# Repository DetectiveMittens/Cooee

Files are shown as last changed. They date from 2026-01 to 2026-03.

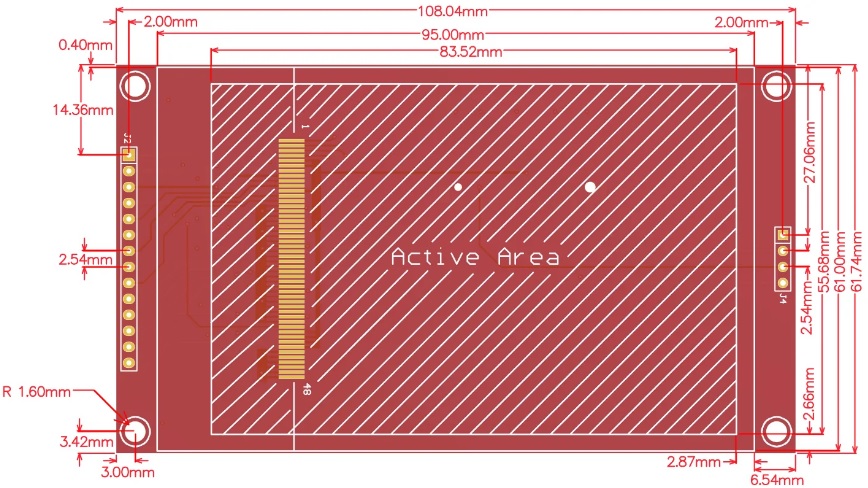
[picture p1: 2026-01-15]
Other Parts/Screen/Elecro_4inch_LCD.jpg

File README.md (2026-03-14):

# Cooee (A LoRa Phone)                           
An open-source phone that can operate without GSM or LTE coverage. Utilising LoRa modulation and mesh networking to enable long range "off-grid" communication.

Come get involved or just chat here! -> [Discord](https://discord.gg/eWgrdjpTFj)
Cooee_renders1

## Target Utilities/Functions
At time of writing (Jan 2026) Popular LoRa mesh networks only aim to support passing of text messages for public and private chat. Cooee aims to provide more of phone the features that consumers are used to

* __Voice calls:__ using 'Codec2' voice can be heavily compressed into small enough packets as to be supported by ~900MHz LoRa bandwidth limitations. Due to the delay that would happen if these packets needed to be retransmitted, calls would likely only be permitted between devices that have only 1 or 0 repeaters required between them.

* __Navigation:__ Using the data from OpenStreetMaps https://www.openstreetmap.org/ pre-loaded onto the device SD card a GPS reciever and infered location data based on signal strength to fixed repeaters of known location, the Cooee device should be able to locate itself well enough for navigation without ever needing a mobile data connection. 

* __Sending images and files:__
While LoRa bandwidth will likely never support sending large files (videos etc) piecemeal file transfers of compressed images (jpgs) should be possible

Cooee_renders2

## Applications / Uses: 
The Cooee should ideally contribute to solving the following problems
  * Distress calls for help in remote locations
  * Basic communication in areas without GSM/LTE infrastructure
  * Dissemination of natural disaster and emergency warnings
  * Marking/Logging GPS locations. Users could tag and share hazards such as landmines (UXO/ERW), fires, vehicle collisions, chemical spills or dangerous wildlife.
  * Navigation in areas without GSM/LTE infrastructure

## Philosophy: 
My dream for this device is that is could demonstrate my ideals for what the future of harware aught to look like. This means deliberately achieving aims in ways which are not the 'best practice', such as;
 * Keeping code simple, using the Arduino framework isntead of ESP-IDF. The idea being that this increases how many people around the world would be able to understand and modify the device firmware, helping ensure that it is kept on track with providing maximum utility to the lives of those people who own one.
 * No electronic components smaller than 805 (no micro-soldering), this allows people to hand solder in repairs and hand assembly the PCB's with minimal equipement
 * SMT components on one side of the PCB only. Again allowing for easy assembly and repair without specialized gear
 * Plastic parts moulded from post consumer waste. Many plastics today claim to be 'recycled' when really they are just 'factory seconds', they have never used and discarded. I would like the plastic components of the Cooee to be injection moulded from recycld post consumer PET bottled pulled from waterways. Many countries in SEA are flooded with drink bottles made of PET. an easily recycled thermoplastic.
 * Hardware ownership. Increasingly, modern mobile devices are not really the property of the customer who paid hundreds, sometimes thousands of dollars to 'own' it. They are not free to modify it or install custom firmware, even creating custom firmware is a task far beyond the capabilities of most. This leaves people at the mercy of whatever bloatware the manufacturers have bundled. This bundled software often; listens to you at all times, sends transcripts of your conversations to corporate servers, advertises products at you, insists on volunteering additional personal details to enable use ect. I think it's high time that the cleverst people in the world put thier efforts towards creating machines that provide all of the utility that benefits us without any of the data harvesting and advertising. Imagine how nice it would be to use a navigator which simply puts your GPS position on a locally loaded map, it doesn't start suffocating your device by chewing up huge amounts of bandwidth or report everywhere you go to a server or try to encourage spending on nearby businesses. Imagine a navigator which just helps you nagivate in the most lightweight and unobtrusive way possible.
 This is the philisophy I want to see applied to all the functions of the Cooee software.

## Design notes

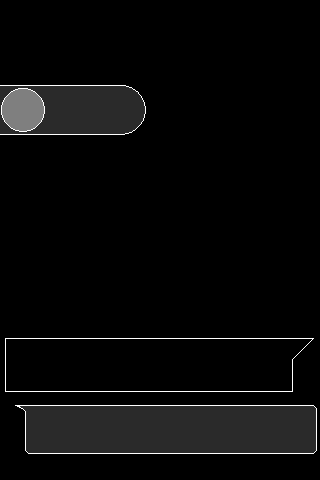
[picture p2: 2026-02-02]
UI_Graphics/messages.bmp

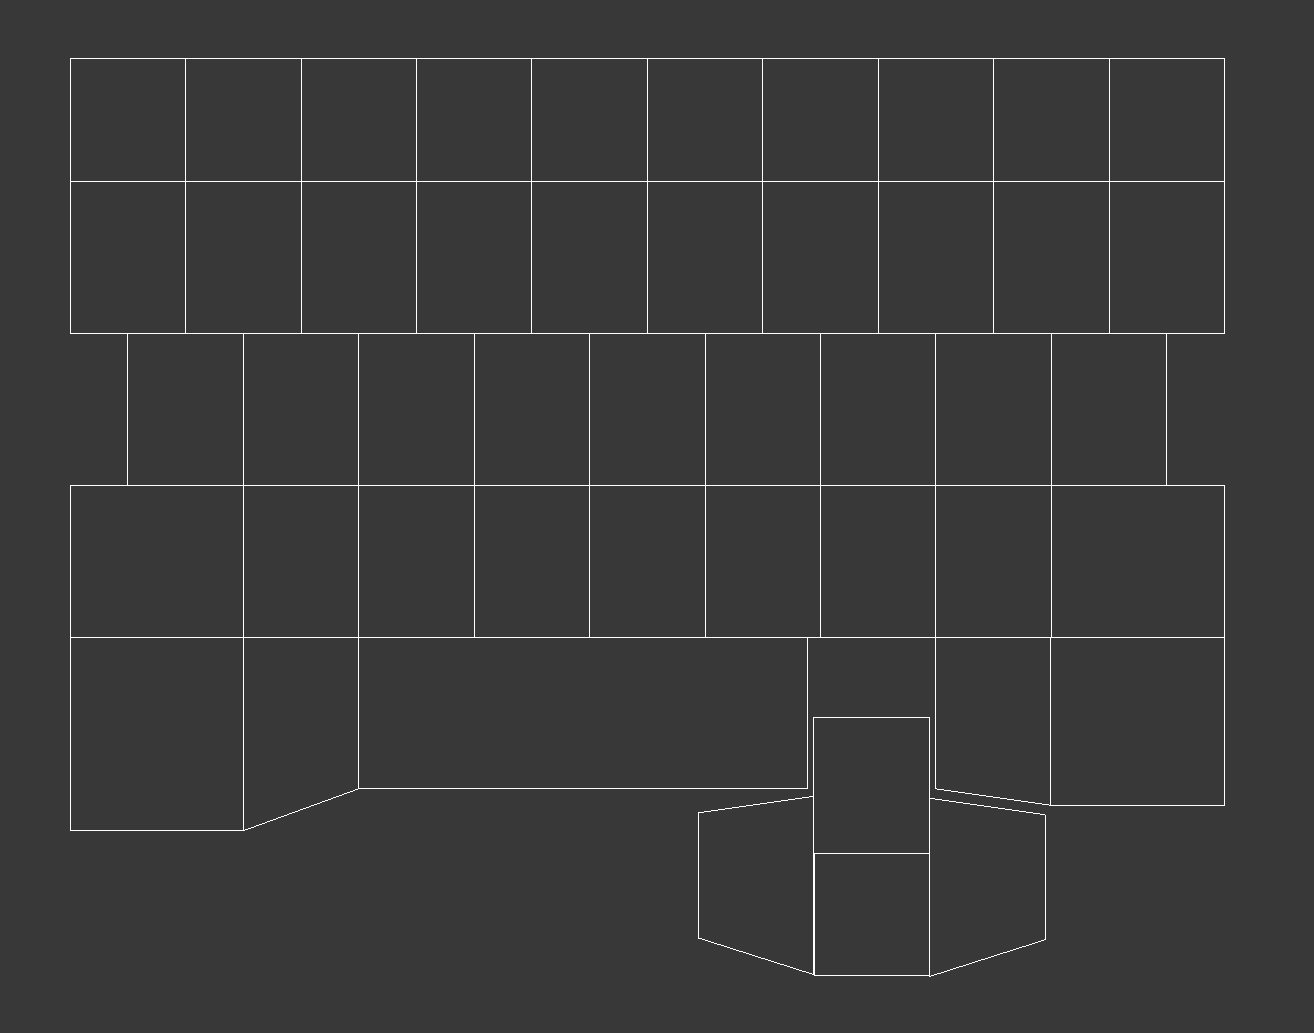
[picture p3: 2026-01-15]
PCB (KiCAD)/key_layout.png

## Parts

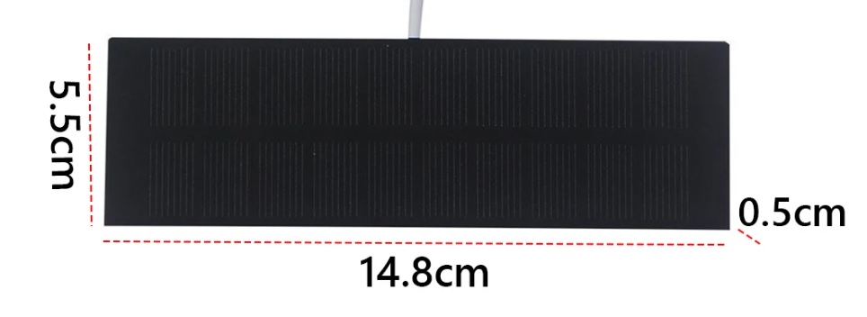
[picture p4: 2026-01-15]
Other Parts/SolarCell/solar_cell.jpg

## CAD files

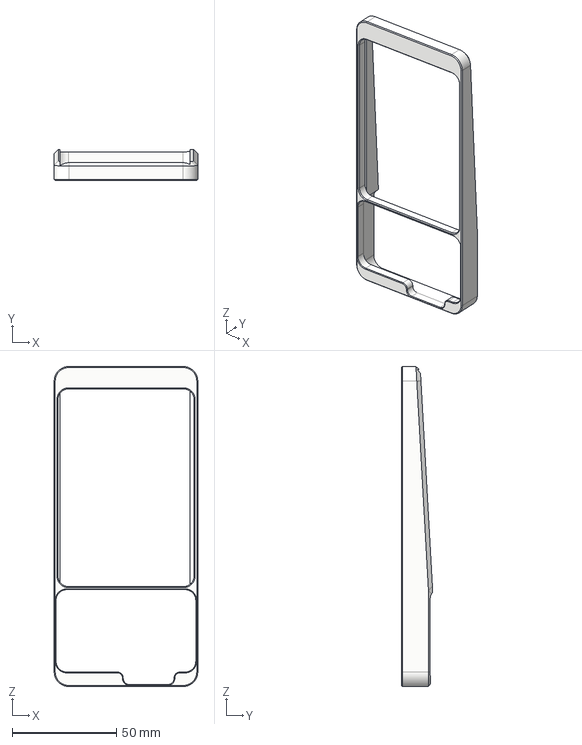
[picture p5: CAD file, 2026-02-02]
3D Prints/Case Prototype.step
68.9 x 15.0 x 153.4 mm

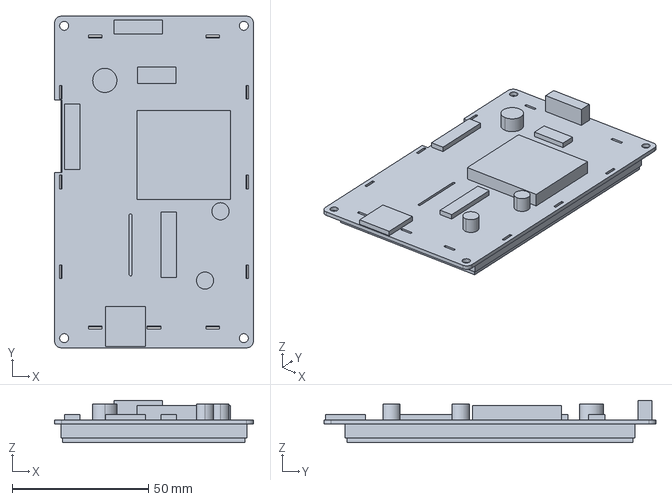
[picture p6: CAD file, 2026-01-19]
Other Parts/Screen/DWIN_DMG48270C043-04WTC.FCStd
73.2 x 121.9 x 15.6 mm

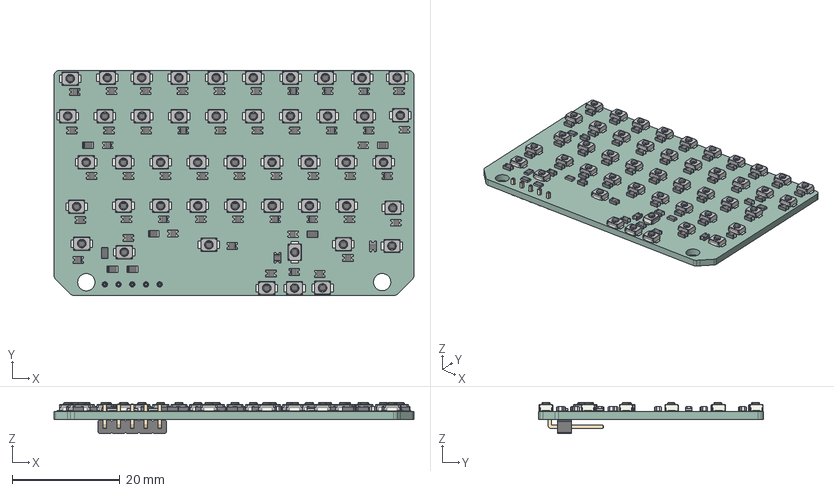
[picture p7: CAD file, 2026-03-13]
PCB (KiCAD)/Cooee_keyboard_68mm.step
66.8 x 41.8 x 5.82 mm
D_0805_2012Metric x 51
SW_SPST_B3U-1000P x 47
R_0805_2012Metric x 7
PinHeader_1x05_P2.54mm_Horizontal
Cooee_keyboard_68mm_PCB

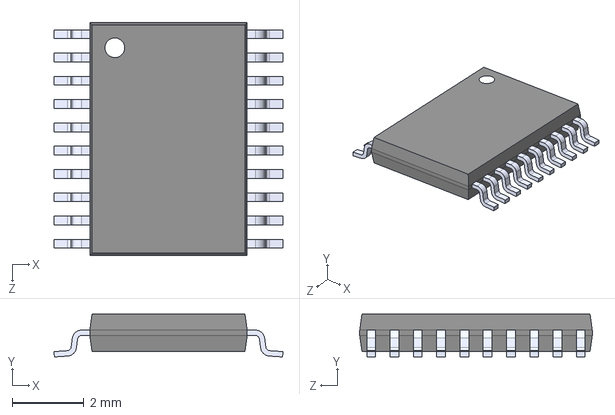
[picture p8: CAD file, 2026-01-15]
PCB (KiCAD)/ICs/PCM5102APWR.STEP
6.40 x 1.20 x 6.50 mm

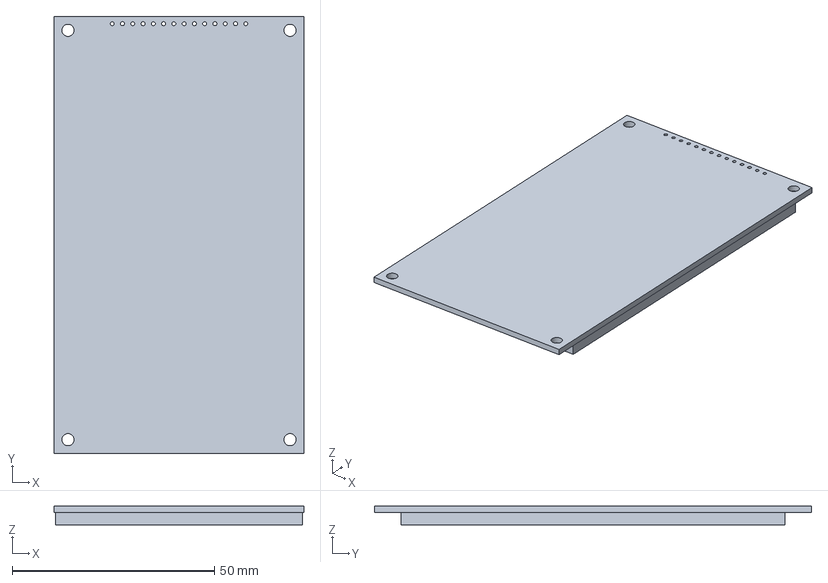
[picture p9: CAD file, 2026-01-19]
Other Parts/Screen/Elecro_4.0_TFT_LCD.FCStd
61.7 x 108.0 x 4.60 mm

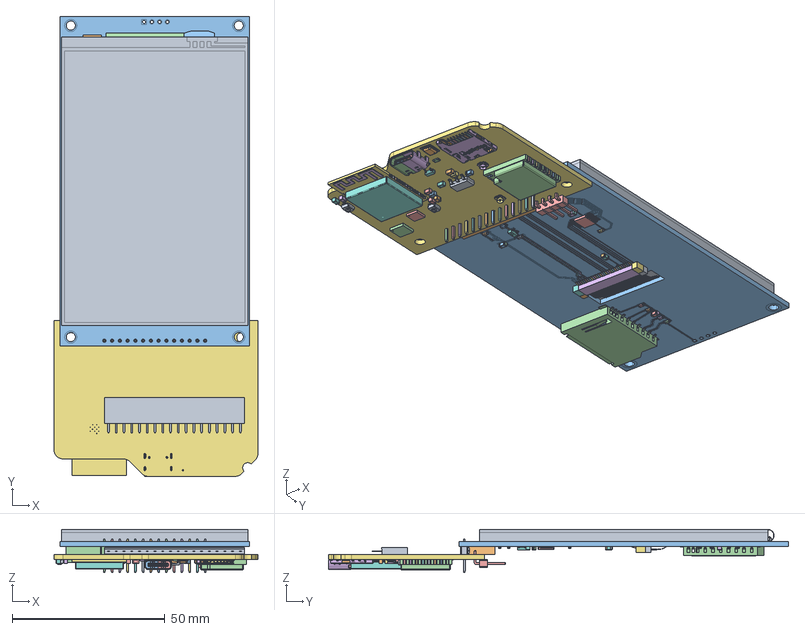
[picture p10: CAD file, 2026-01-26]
PCB (KiCAD)/Cooee_Brains.FCStd
66.8 x 150.7 x 14.2 mm
PinSocket_1x18_P2.54mm_Vertical
PinSocket_1x14_P2.54mm_Horizontal
Cooee_brains 1.3.1
Cooee_brains 1.3.001
Cooee_brains 1.3.002
Cooee_brains 1.3.003
Cooee_brains 1.3.004
Cooee_brains 1.3.005
Cooee_brains 1.3.006
Cooee_brains 1.3.007
Cooee_brains 1.3.008
Cooee_brains 1.3.009
Cooee_brains 1.3.010
Cooee_brains 1.3.011
Cooee_brains 1.3.012
Cooee_brains 1.3.013
Cooee_brains 1.3.014
Cooee_brains 1.3.015
Cooee_brains 1.3.016
Cooee_brains 1.3.017
Cooee_brains 1.3.018
Cooee_brains 1.3.019
Cooee_brains 1.3.020
Cooee_brains 1.3.021
Cooee_brains 1.3.022
Cooee_brains 1.3.023
Cooee_brains 1.3.024
Cooee_brains 1.3.025
Cooee_brains 1.3.026
Cooee_brains 1.3.027
Cooee_brains 1.3.028
Cooee_brains 1.3.029
Cooee_brains 1.3.030
Cooee_brains 1.3.031
Cooee_brains 1.3.032
Cooee_brains 1.3.033
Cooee_brains 1.3.034
Cooee_brains 1.3.035
Cooee_brains 1.3.036
Cooee_brains 1.3.037
Cooee_brains 1.3.038
Cooee_brains 1.3.039
Cooee_brains 1.3.040
Cooee_brains 1.3.041
Cooee_brains 1.3.042
Cooee_brains 1.3.043
Cooee_brains 1.3.044
Cooee_brains 1.3.045
Cooee_brains 1.3.046
Cooee_brains 1.3.047
Cooee_brains 1.3.048
Cooee_brains 1.3.049
Cooee_brains 1.3.050
Cooee_brains 1.3.051
Cooee_brains 1.3.052
Cooee_brains 1.3.053
Cooee_brains 1.3.054
Cooee_brains 1.3.055
Cooee_brains 1.3.056
Cooee_brains 1.3.057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

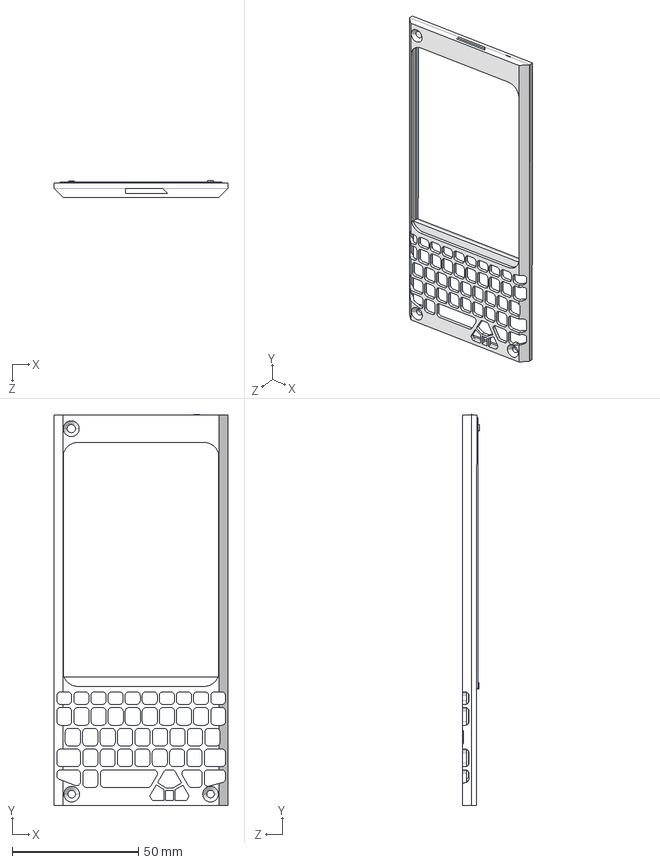
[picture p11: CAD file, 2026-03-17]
Plastic Parts (FreeCAD)/Faceplante_Test2.STEP
68.8 x 154.6 x 6.57 mm

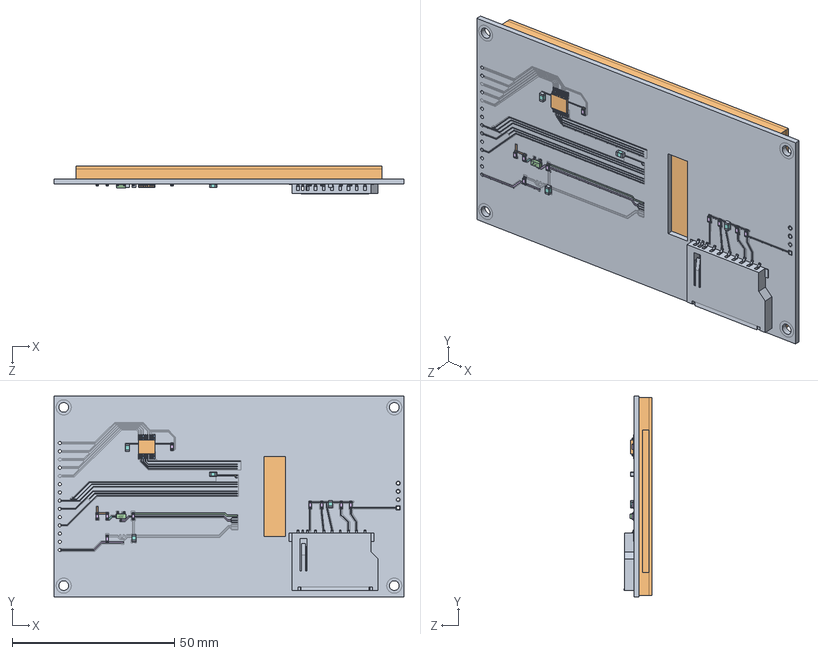
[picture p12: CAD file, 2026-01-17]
Other Parts/Screen/LCD ILI9488 4.0_Simpler.STEP
108.0 x 62.0 x 8.69 mm
pcb_lcd.stp
K_ARDUINO_SD-SCHACHT.stp
XPT204.stp
J3Y.stp
resistor2.stp x 9
ceramic2.stp x 4
tft.stp

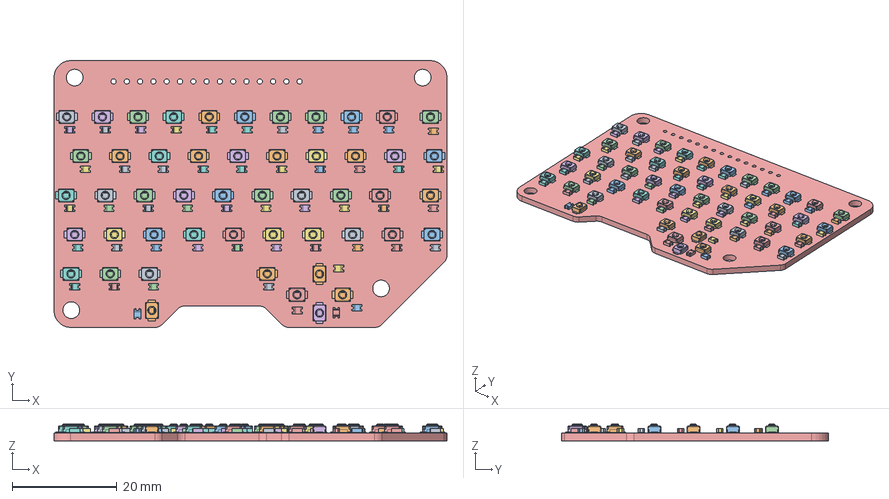
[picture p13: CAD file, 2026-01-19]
PCB (KiCAD)/PCB_Keyboard.FCStd
75.1 x 51.0 x 3.20 mm
D_0805_2012Metric
SW_SPST_B3U-1000P
D_0805_2012Metric001
D_0805_2012Metric002
D_0805_2012Metric003
D_0805_2012Metric004
SW_SPST_B3U-1000P001
SW_SPST_B3U-1000P002
D_0805_2012Metric005
SW_SPST_B3U-1000P003
SW_SPST_B3U-1000P004
SW_SPST_B3U-1000P005
SW_SPST_B3U-1000P006
D_0805_2012Metric006
D_0805_2012Metric007
D_0805_2012Metric008
D_0805_2012Metric009
SW_SPST_B3U-1000P007
D_0805_2012Metric010
SW_SPST_B3U-1000P008
D_0805_2012Metric011
D_0805_2012Metric012
D_0805_2012Metric013
SW_SPST_B3U-1000P009
D_0805_2012Metric014
SW_SPST_B3U-1000P010
SW_SPST_B3U-1000P011
SW_SPST_B3U-1000P012
SW_SPST_B3U-1000P013
SW_SPST_B3U-1000P014
D_0805_2012Metric015
SW_SPST_B3U-1000P015
D_0805_2012Metric016
SW_SPST_B3U-1000P016
SW_SPST_B3U-1000P017
SW_SPST_B3U-1000P018
SW_SPST_B3U-1000P019
SW_SPST_B3U-1000P020
D_0805_2012Metric017
D_0805_2012Metric018
D_0805_2012Metric019
SW_SPST_B3U-1000P021
D_0805_2012Metric020
SW_SPST_B3U-1000P022
D_0805_2012Metric021
SW_SPST_B3U-1000P023
SW_SPST_B3U-1000P024
D_0805_2012Metric022
SW_SPST_B3U-1000P025
SW_SPST_B3U-1000P026
SW_SPST_B3U-1000P027
D_0805_2012Metric023
D_0805_2012Metric024
D_0805_2012Metric025
D_0805_2012Metric026
SW_SPST_B3U-1000P028
SW_SPST_B3U-1000P029
D_0805_2012Metric027
D_0805_2012Metric028
D_0805_2012Metric029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

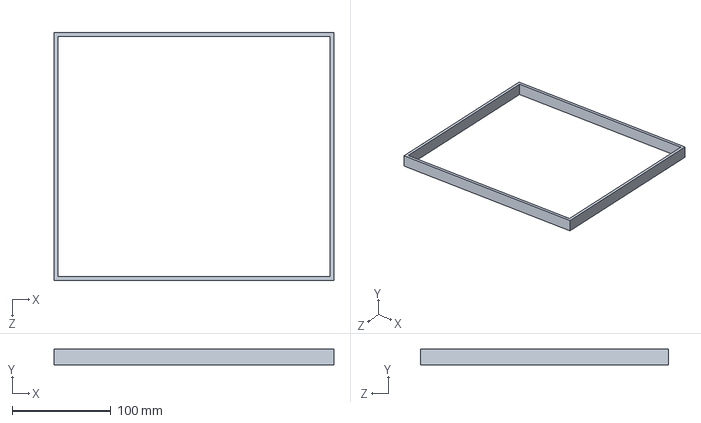
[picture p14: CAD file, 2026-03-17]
Plastic Parts (FreeCAD)/Centering_Frame.SLDPRT
284.1 x 16.0 x 252.0 mm

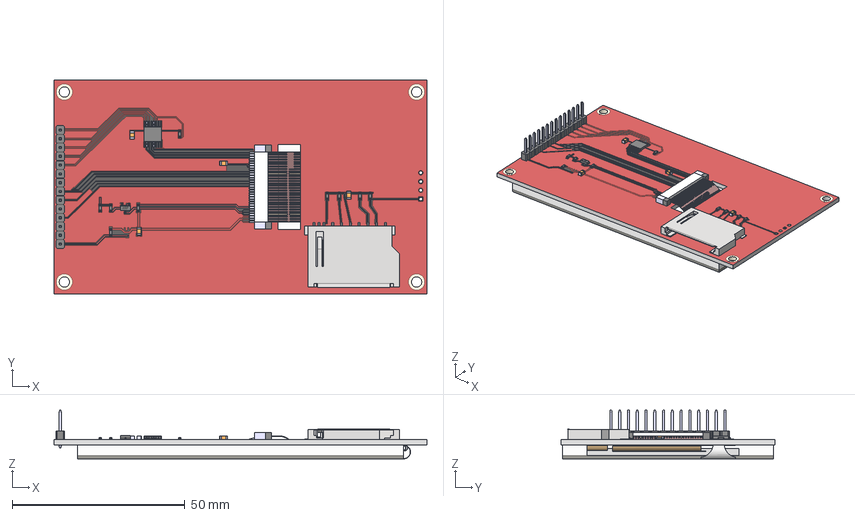
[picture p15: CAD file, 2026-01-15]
Other Parts/Screen/LCD ILI9488 4.0.stp
108.0 x 62.0 x 14.1 mm
pcb_lcd
K_ARDUINO_SD-SCHACHT
XPT204
Connector
J3Y
PINx14
resistor2 x 9
ceramic2 x 4
tft
ribbon_cable_1

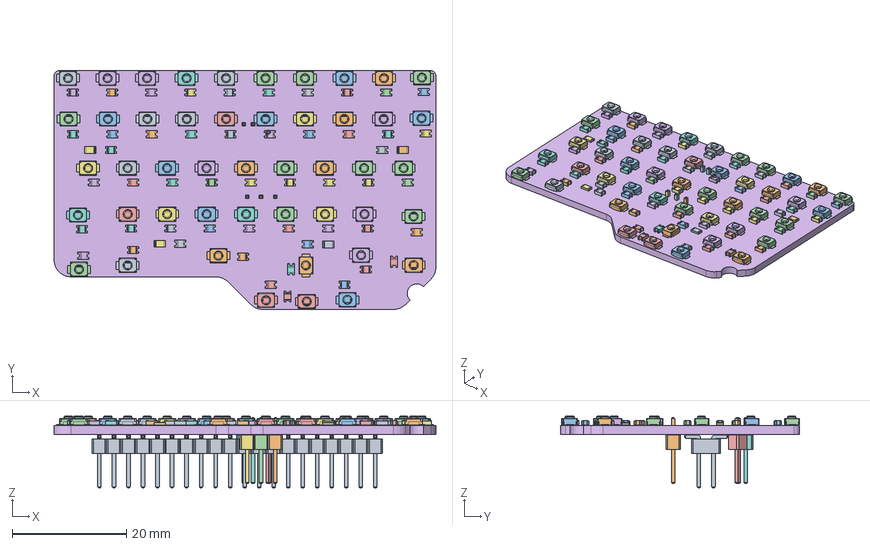
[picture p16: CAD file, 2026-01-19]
PCB (KiCAD)/PCB_Keyboard_68mm.FCStd
66.8 x 41.8 x 12.6 mm
D_0805_2012Metric
SW_SPST_B3U-1000P
D_0805_2012Metric001
D_0805_2012Metric002
D_0805_2012Metric003
D_0805_2012Metric004
SW_SPST_B3U-1000P001
SW_SPST_B3U-1000P002
D_0805_2012Metric005
D_0805_2012Metric006
SW_SPST_B3U-1000P003
SW_SPST_B3U-1000P004
SW_SPST_B3U-1000P005
D_0805_2012Metric007
D_0805_2012Metric008
D_0805_2012Metric009
D_0805_2012Metric010
SW_SPST_B3U-1000P006
D_0805_2012Metric011
SW_SPST_B3U-1000P007
D_0805_2012Metric012
D_0805_2012Metric013
D_0805_2012Metric014
SW_SPST_B3U-1000P008
SW_SPST_B3U-1000P009
SW_SPST_B3U-1000P010
SW_SPST_B3U-1000P011
SW_SPST_B3U-1000P012
SW_SPST_B3U-1000P013
D_0805_2012Metric015
SW_SPST_B3U-1000P014
D_0805_2012Metric016
SW_SPST_B3U-1000P015
SW_SPST_B3U-1000P016
SW_SPST_B3U-1000P017
SW_SPST_B3U-1000P018
SW_SPST_B3U-1000P019
D_0805_2012Metric017
R_0805_2012Metric
D_0805_2012Metric018
R_0805_2012Metric001
D_0805_2012Metric019
SW_SPST_B3U-1000P020
SW_SPST_B3U-1000P021
D_0805_2012Metric020
SW_SPST_B3U-1000P022
SW_SPST_B3U-1000P023
D_0805_2012Metric021
D_0805_2012Metric022
SW_SPST_B3U-1000P024
SW_SPST_B3U-1000P025
SW_SPST_B3U-1000P026
D_0805_2012Metric023
D_0805_2012Metric024
D_0805_2012Metric025
D_0805_2012Metric026
SW_SPST_B3U-1000P027
D_0805_2012Metric027
D_0805_2012Metric028
D_0805_2012Metric029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

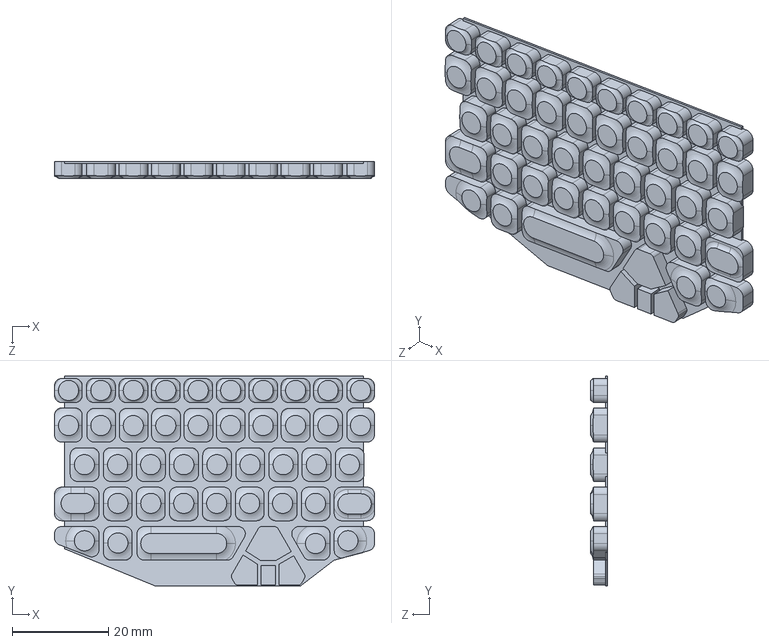
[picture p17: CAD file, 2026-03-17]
Plastic Parts (FreeCAD)/Keys_Test1.STEP
66.6 x 43.7 x 3.45 mm

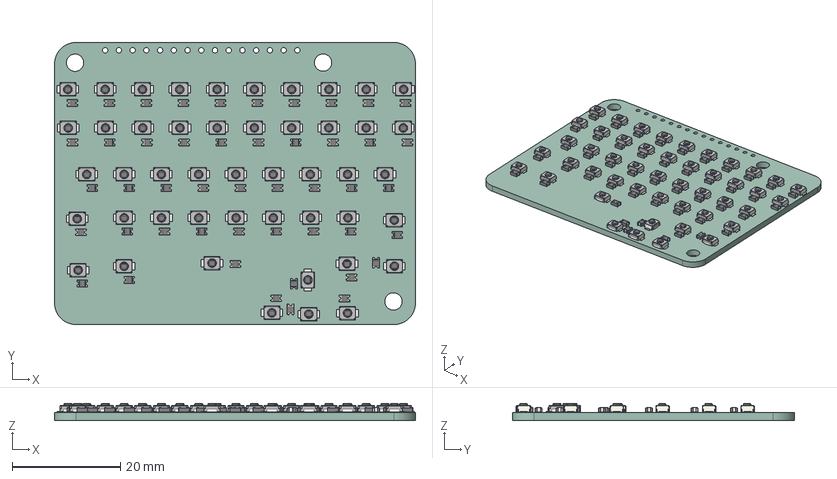
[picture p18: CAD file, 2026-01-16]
PCB (KiCAD)/Cooee_keyboard.step
66.8 x 52.2 x 3.20 mm
D_0805_2012Metric x 47
SW_SPST_B3U-1000P x 47
Cooee_keyboard_68mm_PCB

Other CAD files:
Plastic Parts (FreeCAD)/Case_Assembly.FCStd
Plastic Parts (FreeCAD)/keyboard_outline.DXF
Other Parts/Screen/3D-DMG48270C043-04WTC.stp
Plastic Parts (FreeCAD)/Case2.SLDPRT
Other Parts/Battery/18650.FCStd
PCB (KiCAD)/Cooee_keyboard_75mm.step
Plastic Parts (FreeCAD)/Case.FCStd
Plastic Parts (FreeCAD)/Case2.SLDDRW
Plastic Parts (FreeCAD)/CaseTest.SLDPRT
Plastic Parts (FreeCAD)/Case_2.FCStd
Plastic Parts (FreeCAD)/Motherboard_wScreen.FCStd
Plastic Parts (FreeCAD)/Torch_Lens.SLDPRT

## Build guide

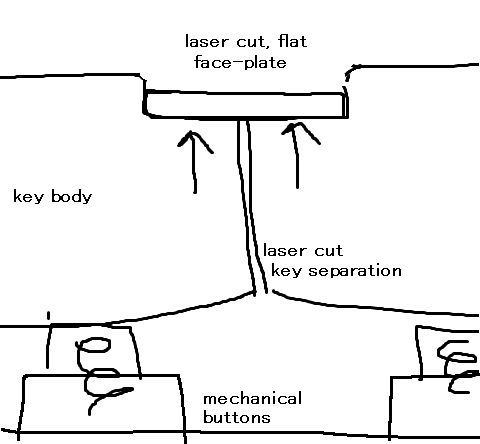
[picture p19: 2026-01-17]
Plastic Parts (FreeCAD)/kayboard_manufacture_plan.jpg

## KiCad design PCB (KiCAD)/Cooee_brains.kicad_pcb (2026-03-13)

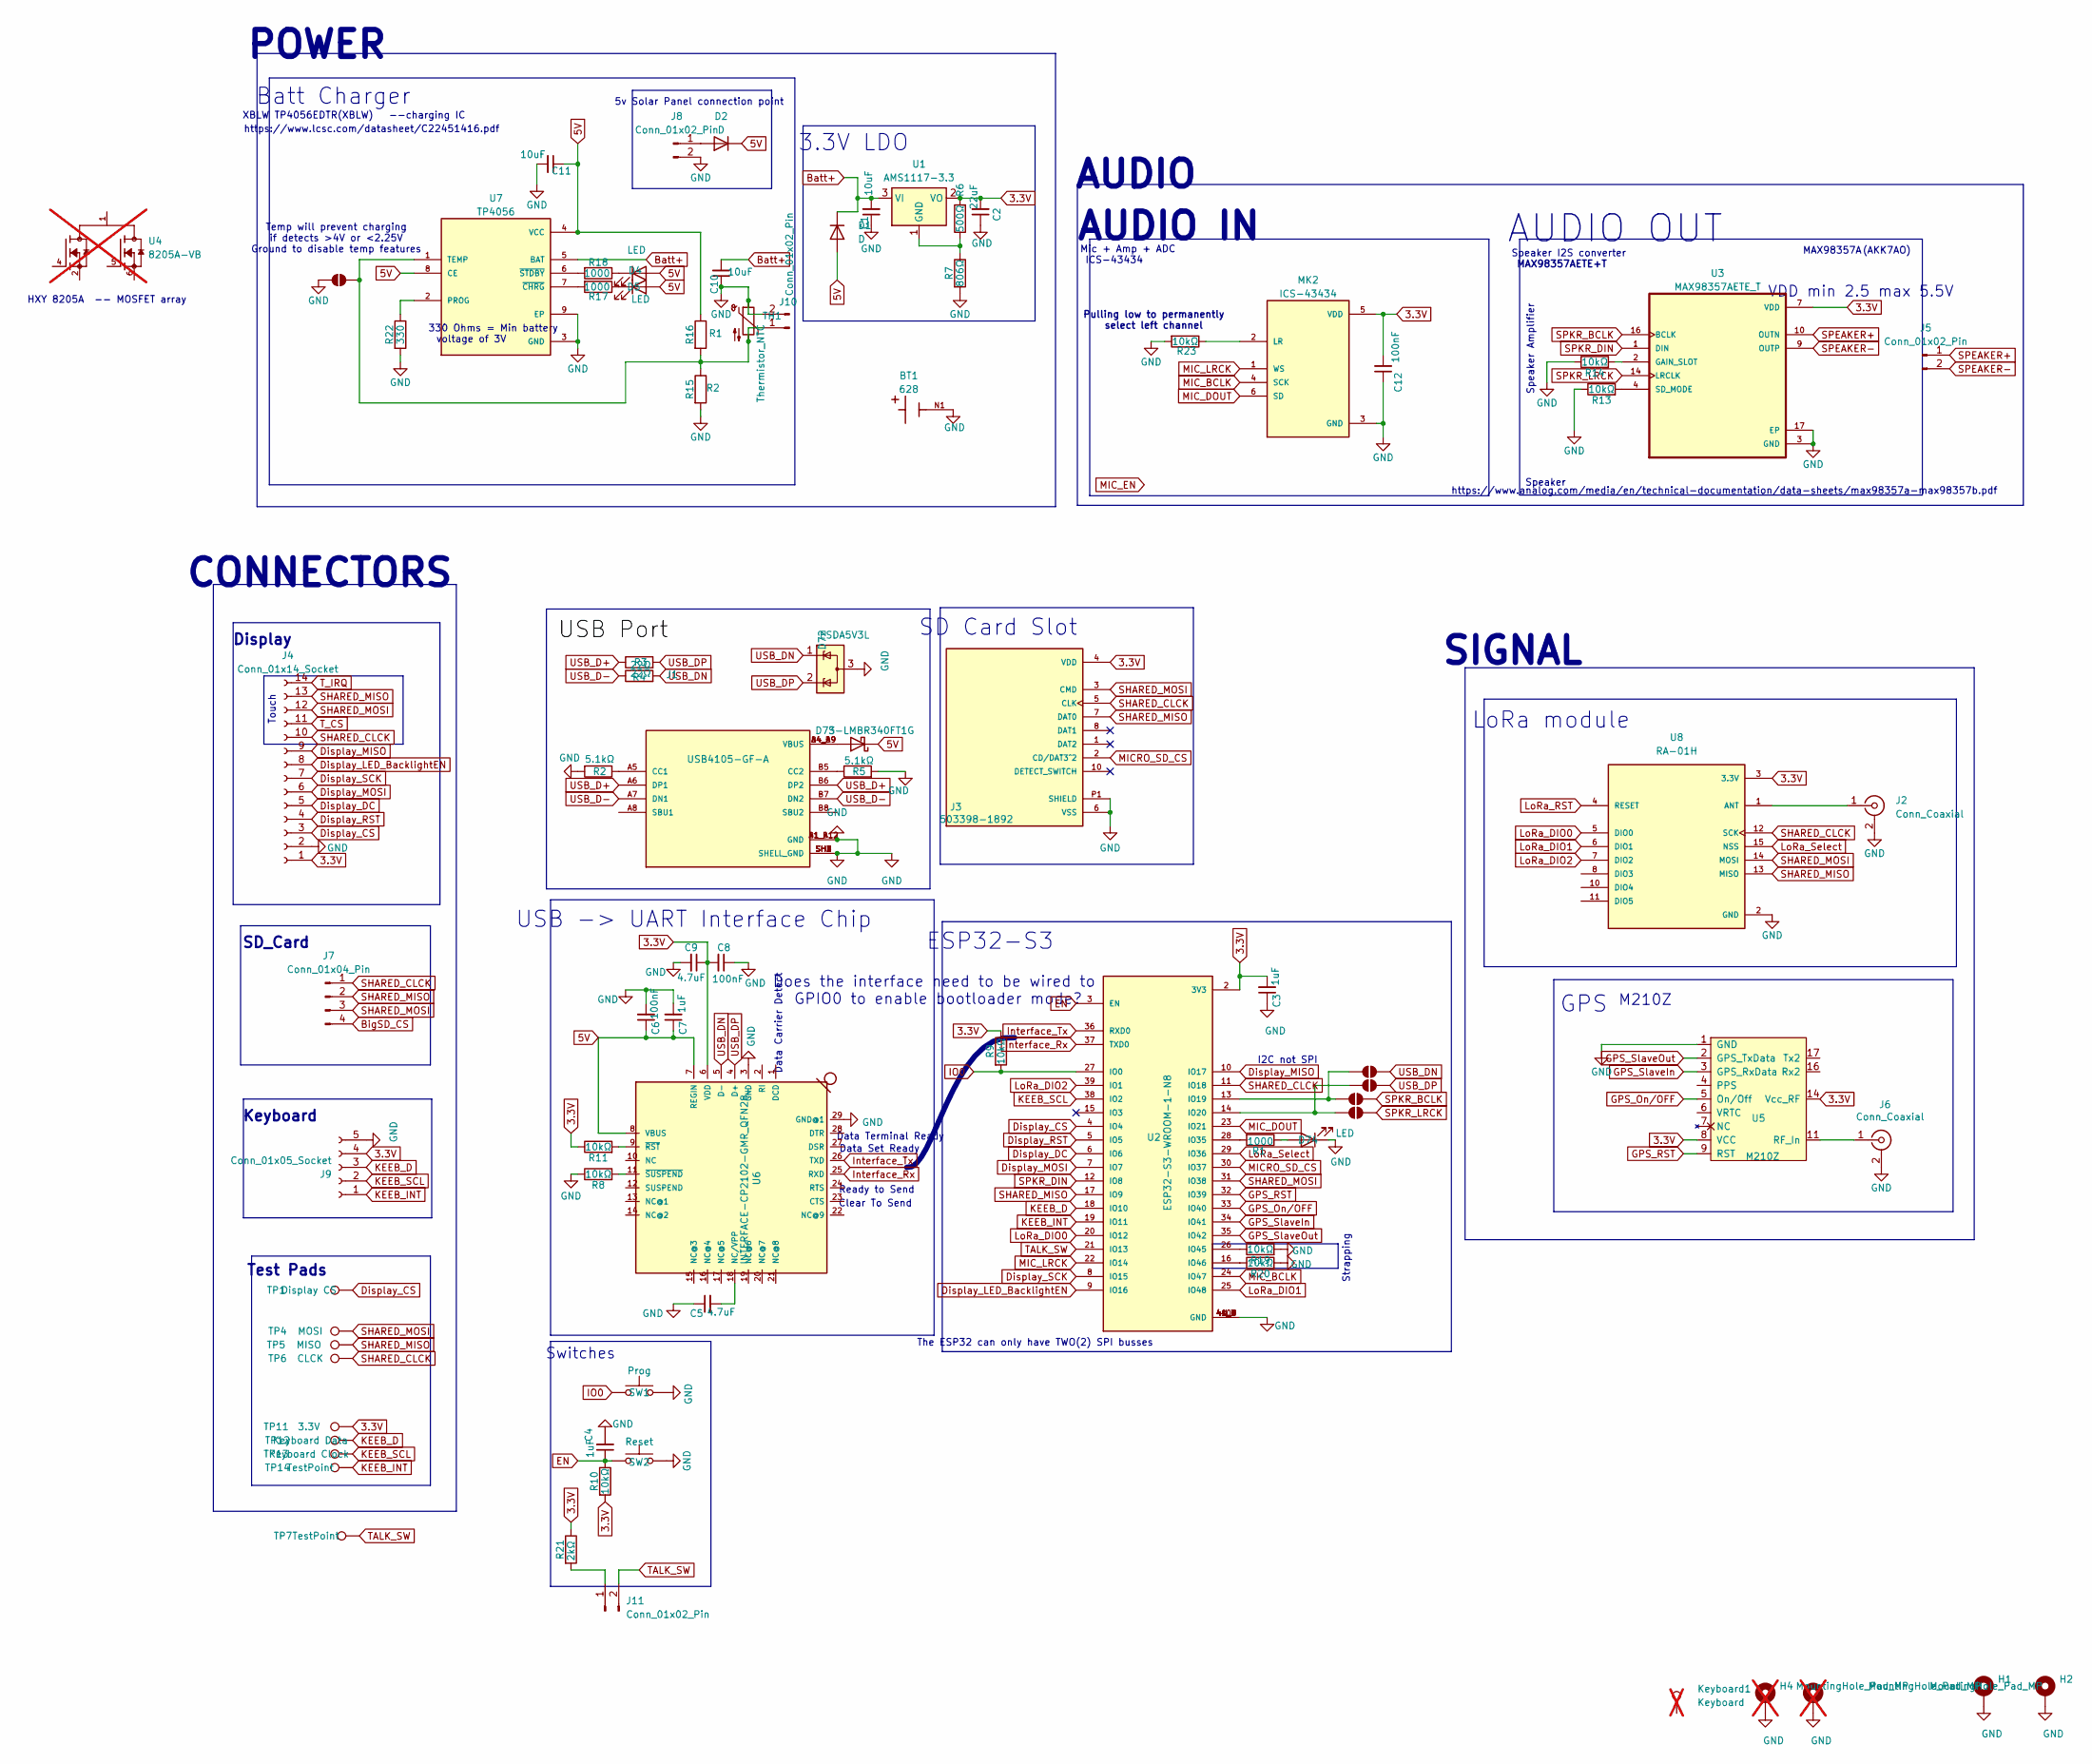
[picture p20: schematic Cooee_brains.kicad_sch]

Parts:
BT1: 628; BAT_628; PARTREV A; DigiKey_Part_Number 36-628-ND
C1, C10, C11: 10uF; C_0805_2012Metric
C2: 22uF; C_0805_2012Metric
C3, C7: 1uF; C_0805_2012Metric
C4: 1uF; C_0805_2012Metric_Pad1.18x1.45mm_HandSolder
C5, C9: 4.7uF; C_0805_2012Metric
C6, C8, C12: 100nF; C_0805_2012Metric
D1, D2: D; D_0805_2012Metric_Pad1.15x1.40mm_HandSolder
D4, D5, D74: LED; C_0805_2012Metric
D72: ESDA5V3L; SOT-23_Handsoldering
D73: S-LMBR340FT1G; D_SOD-123FL
H1, H2: MountingHole_Pad_MP; MountingHole_3.2mm_M3_DIN965_Pad_TopBottom
H3, H4: MountingHole_Pad_MP; MountingHole_3.2mm_M3_DIN965_Pad_TopBottom; not fitted
J1: USB4105-GF-A; USB_C_Receptacle_GCT_USB4105-xx-A_16P_TopMnt_Horizontal
J2, J6: Conn_Coaxial; U.FL_Molex_MCRF_73412-0110_Vertical
J3: 503398-1892; MOLEX_503398-1892; PARTREV 0
J4: Conn_01x14_Socket; PinSocket_1x14_P2.54mm_Horizontal
J5, J8, J10, J11: Conn_01x02_Pin; PinHeader_1x02_P2.54mm_Horizontal
J7: Conn_01x04_Pin; PinHeader_1x04_P2.54mm_Horizontal
J9: Conn_01x05_Socket; PinSocket_1x05_P2.54mm_Horizontal
JP1, JP2, JP3, JP4, JP5: SolderJumper_2_Open; SolderJumper-2_P1.3mm_Open_RoundedPad1.0x1.5mm
Keyboard1: Keyboard; TestPoint_Pad_1.0x1.0mm; not fitted
MK2: ICS-43434; MIC_ICS-43434
R1, R17, R18: 1000; C_0805_2012Metric_Pad1.18x1.45mm_HandSolder
R2, R5: 5.1kΩ; R_0805_2012Metric
R3, R4: 22Ω; R_0805_2012Metric
R6: 500Ω; C_0805_2012Metric_Pad1.18x1.45mm_HandSolder
R7: 806Ω; C_0805_2012Metric_Pad1.18x1.45mm_HandSolder
R8, R9, R10, R11, R13, R14, R19, R20, R23: 10kΩ; C_0805_2012Metric_Pad1.18x1.45mm_HandSolder
R15: R2; C_0805_2012Metric_Pad1.18x1.45mm_HandSolder
R16: R1; C_0805_2012Metric_Pad1.18x1.45mm_HandSolder
R21: 2kΩ; C_0805_2012Metric_Pad1.18x1.45mm_HandSolder
R22: 330; C_0805_2012Metric_Pad1.18x1.45mm_HandSolder
SW1: Prog; SW_SPST_B3U-1000P_MovedText
SW2: Reset; SW_SPST_B3U-1000P_MovedText
TH1: Thermistor_NTC; R_0805_2012Metric_Pad1.20x1.40mm_HandSolder
TP1: Display CS; TestPoint_Pad_1.0x1.0mm
TP4: MOSI; TestPoint_Pad_1.0x1.0mm
TP5: MISO; TestPoint_Pad_1.0x1.0mm
TP6: CLCK; TestPoint_Pad_1.0x1.0mm
TP7, TP14: TestPoint; TestPoint_Pad_1.0x1.0mm
TP11: 3.3V; TestPoint_Pad_1.0x1.0mm
TP12: Keyboard Data; TestPoint_Pad_1.0x1.0mm
TP13: Keyboard Clock; TestPoint_Pad_1.0x1.0mm
U1: AMS1117-3.3; SOT-223-3_TabPin2
U2: ESP32-S3-WROOM-1-N8; ESP32-S3-WROOM-1
U3: MAX98357AETE_T; TQFN-16-1EP_3x3mm_P0.5mm_EP1.6x1.6mm
U4: 8205A-VB; SOP65P640X120-8N; PARTREV NA; not fitted
U5: M210Z
U6: INTERFACE-CP2102-GMR_QFN28_; QFN28G_0.5-5X5MM; MPN CP2102-GMR
U7: TP4056; SOP127P600X175-9N
U8: RA-01H; Ai-Thinker-Ra-01-LoRa; PARTREV V1.0; DigiKey_Part_Number 4570-RA-01HCT-ND

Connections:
3.3V: C2.2, C3.2, C8.2, C9.1, C12.2, J3.4 (VDD), J4.1, J9.4, MK2.5 (VDD), R6.2, R9.1, R10.2, R11.1, R21.1, TP11.1, U1.2 (VO), U2.2 (3V3), U3.7 (VDD), U3.8 (VDD), U5.8 (VCC), U5.14 (Vcc_RF), U6.6 (VDD), U8.3 (3.3V)
5V: C6.1, C7.1, C11.1, D1.2 (A), D2.1 (K), D4.2 (A), D5.2 (A), D73.1 (K), R16.1, U6.7 (REGIN), U6.8 (VBUS), U7.4 (VCC), U7.8 (CE)
Batt+: C1.2, C10.2, D1.1 (K), U1.3 (VI), U7.5 (BAT)
BigSD_CS: J7.4
Display_CS: J4.3, TP1.1, U2.4 (IO4)
Display_DC: J4.5, U2.6 (IO6)
Display_LED_BacklightEN: J4.8, U2.9 (IO16)
Display_MISO: J4.9, U2.10 (IO17)
Display_MOSI: J4.6, U2.7 (IO7)
Display_RST: J4.4, U2.5 (IO5)
Display_SCK: J4.7, U2.8 (IO15)
EN: C4.1, R10.1, SW2.1, U2.3 (EN)
GND: BT1.N1, BT1.N2, BT1.N3, C1.1, C2.1, C3.1, C4.2, C5.1, C6.2, C7.2, C8.1, C9.2, C10.1, C11.2, C12.1, D72.3 (A), D74.1 (K), H1.1, H1.MP, H2.1, H2.MP, H3.MP, H4.MP, J1.A1_B12 (GND), J1.B1_A12 (GND), J1.S1, J1.SH1 (SHELL_GND), J1.SH2 (SHELL_GND), J1.SH3 (SHELL_GND), J1.SH4 (SHELL_GND), J2.2 (Ext), J3.6 (VSS), J3.9 (VSS), J3.P1 (SHIELD), J3.P2 (SHIELD), J3.P3 (SHIELD), J3.P4 (SHIELD), J4.2, J6.2 (Ext), J8.2, J9.5, J10.2, JP5.1 (A), MK2.3 (GND), R2.2, R5.2, R7.2, R8.1, R13.1, R14.1, R15.2, R19.2, R20.2, R22.2, R23.2, SW1.2, SW2.2, TH1.1, U2.1 (GND), U2.40 (GND), U2.41, U2.41_1 (GND), U2.41_2 (GND), U2.41_3 (GND), U2.41_4 (GND), U2.41_5 (GND), U2.41_6 (GND), U2.41_7 (GND), U2.41_8 (GND), U2.41_9 (GND), U2.GND, U3.3 (GND), U3.11 (GND), U3.15 (GND), U3.17 (EP), U5.1 (GND), U6.3 (GND), U6.29 (GND@1), U7.3 (GND), U7.9 (EP), U8.2 (GND), U8.9 (GND), U8.16 (GND)
GPS_On/OFF: U2.33 (IO40), U5.5 (On/Off)
GPS_RST: U2.32 (IO39), U5.9 (RST)
GPS_SlaveIn: U2.34 (IO41), U5.3 (GPS_RxData)
GPS_SlaveOut: U2.35 (IO42), U5.2 (GPS_TxData)
IO0: R9.2, SW1.1, U2.27 (IO0)
Interface_Rx: U2.37 (TXD0), U6.25 (RXD)
Interface_Tx: U2.36 (RXD0), U6.26 (TXD)
KEEB_D: J9.3, TP12.1, U2.18 (IO10)
KEEB_INT: J9.1, TP14.1, U2.19 (IO11)
KEEB_SCL: J9.2, TP13.1, U2.38 (IO2)
LoRa_DIO0: U2.20 (IO12), U8.5 (DIO0)
LoRa_DIO1: U2.25 (IO48), U8.6 (DIO1)
LoRa_DIO2: U2.39 (IO1), U8.7 (DIO2)
LoRa_RST: U8.4 (RESET)
LoRa_Select: U2.29 (IO36), U8.15 (NSS)
MICRO_SD_CS: J3.2 (CD/DAT3^2), U2.30 (IO37)
MIC_BCLK: MK2.4 (SCK), U2.24 (IO47)
MIC_DOUT: MK2.6 (SD), U2.23 (IO21)
MIC_LRCK: MK2.1 (WS), U2.22 (IO14)
unnamed: D2.2 (A), J8.1
unnamed: D4.1 (K), R18.1
unnamed: D5.1 (K), R17.1
unnamed: D73.2 (A), J1.A4_B9 (VBUS), J1.B4_A9 (VBUS)
unnamed: D74.2 (A), R1.1
unnamed: J1.A5 (CC1), R2.1
unnamed: J1.B5 (CC2), R5.1
unnamed: J2.1 (In), U8.1 (ANT)
unnamed: J6.1 (In), U5.11 (RF_In)
unnamed: J10.1, JP5.2 (B), R15.1, R16.2, TH1.2, U7.1 (TEMP)
unnamed: J11.1, R21.2
unnamed: JP1.1 (A), JP3.1 (A), U2.13 (IO19)
unnamed: JP2.1 (A), JP4.1 (A), U2.14 (IO20)
unnamed: MK2.2 (LR), R23.1
unnamed: R6.1, R7.1, U1.1 (GND)
unnamed: R1.2, U2.28 (IO35)
unnamed: R19.1, U2.26 (IO45)
unnamed: R20.1, U2.16 (IO46)
unnamed: R14.2, U3.2 (GAIN_SLOT)
unnamed: R13.2, U3.4 (SD_MODE)
unnamed: U4.1, U4.8
unnamed: U4.2, U4.3
unnamed: U4.6, U4.7
unnamed: C5.2, U6.18 (NC/VPP)
unnamed: R11.2, U6.9 (~RST)
unnamed: R8.2, U6.11 (~SUSPEND)
unnamed: R22.1, U7.2 (PROG)
unnamed: R17.2, U7.7 (~CHRG)
unnamed: R18.2, U7.6 (~STDBY)
SHARED_CLCK: J3.5 (CLK), J4.10, J7.1, TP6.1, U2.11 (IO18), U8.12 (SCK)
SHARED_MISO: J3.7 (DAT0), J4.13, J7.2, TP5.1, U2.17 (IO9), U8.13 (MISO)
SHARED_MOSI: J3.3 (CMD), J4.12, J7.3, TP4.1, U2.31 (IO38), U8.14 (MOSI)
SPEAKER+: J5.1, U3.10 (OUTN)
SPEAKER-: J5.2, U3.9 (OUTP)
SPKR_BCLK: JP3.2 (B), U3.16 (BCLK)
SPKR_DIN: U2.12 (IO8), U3.1 (DIN)
SPKR_LRCK: JP4.2 (B), U3.14 (LRCLK)
TALK_SW: J11.2, TP7.1, U2.21 (IO13)
T_CS: J4.11
T_IRQ: J4.14
USB_D+: J1.A6 (DP1), J1.B6 (DP2), R3.1
USB_D-: J1.A7 (DN1), J1.B7 (DN2), R4.1
USB_DN: D72.1 (K), JP1.2 (B), R4.2, U6.5 (D-)
USB_DP: D72.2 (K), JP2.2 (B), R3.2, U6.4 (D+)

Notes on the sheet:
SIGNAL
Does the interface need to be wired to GPIO0 to enable bootloader mode?
Data Set Ready
MAX98357AETE+T
Data Carrier Detect
AUDIO
The ESP32 can only have TWO(2) SPI busses
https://www.analog.com/media/en/technical-documentation/data-sheets/max98357a-max98357b.pdf
POWER
Speaker Amplifier
M210Z
https://www.lcsc.com/datasheet/C22451416.pdf
voltage of 3V
XBLW TP4056EDTR(XBLW) --charging IC
Strapping
AUDIO IN
Speaker I2S converter
ESP32-S3
Switches
ICS-43434
HXY 8205A -- MOSFET array
SD Card Slot
Ready to Send
Speaker
VDD min 2.5 max 5.5V
Clear To Send
I2C not SPI
SD_Card
5v Solar Panel connection point
AUDIO OUT
Batt Charger
CONNECTORS
Temp will prevent charging if detects >4V or <2.25V Ground to disable temp features
Pulling low to permanently select left channel
USB -> UART Interface Chip
Keyboard
3.3V LDO
Touch
GPS
Test Pads

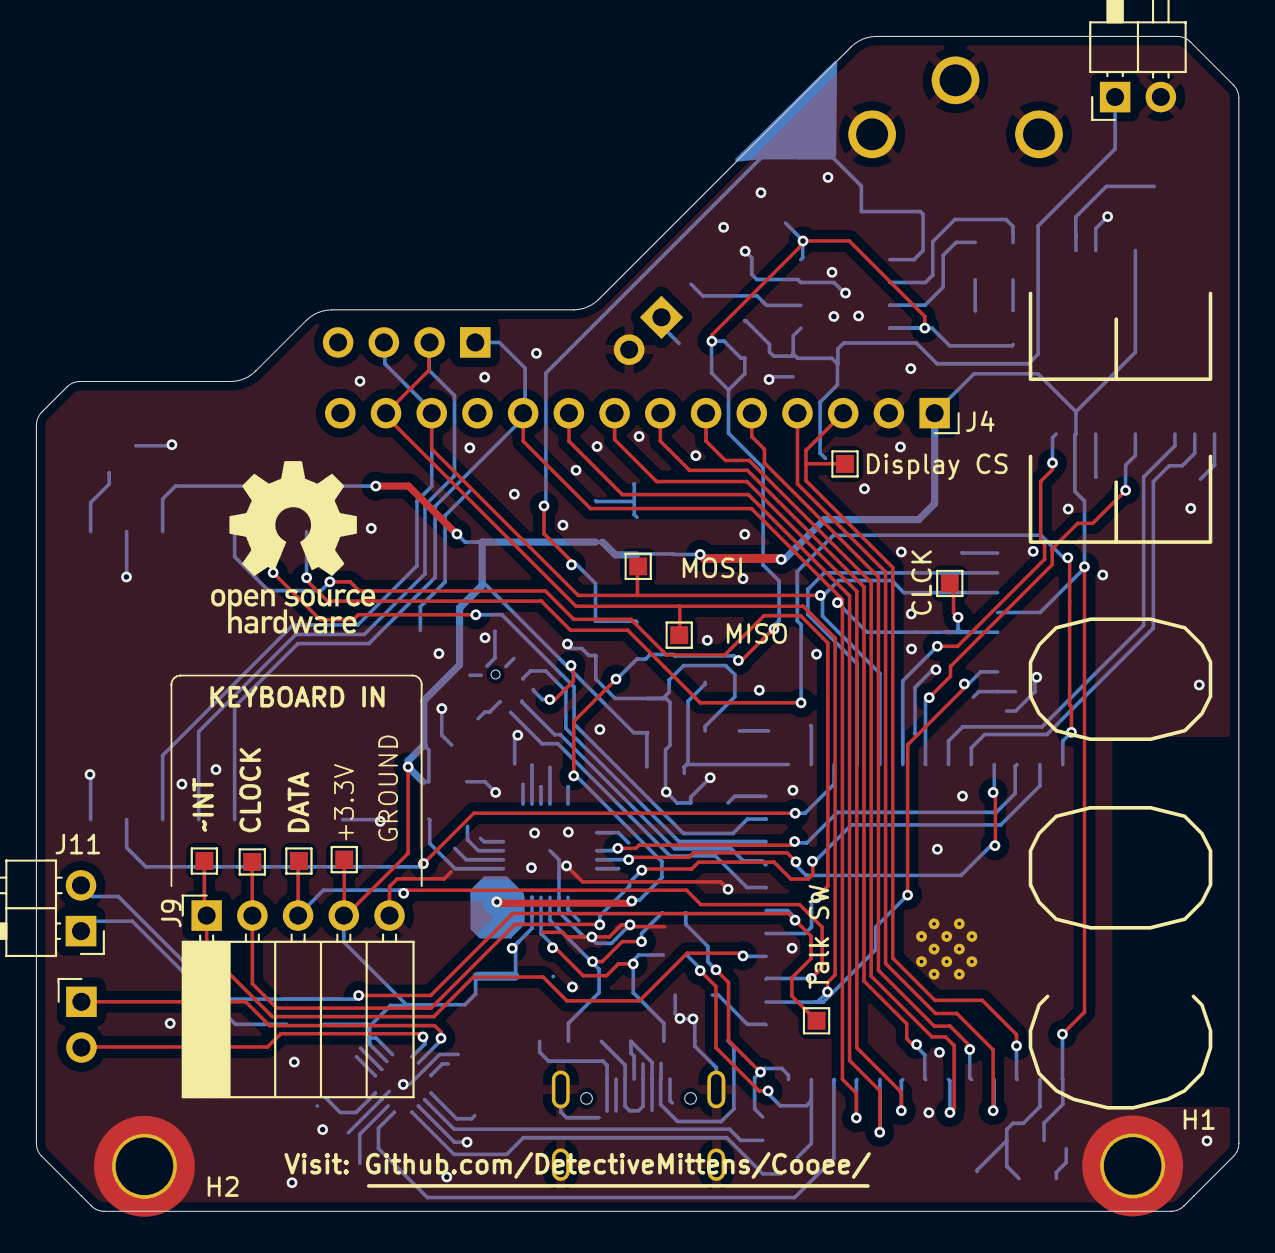
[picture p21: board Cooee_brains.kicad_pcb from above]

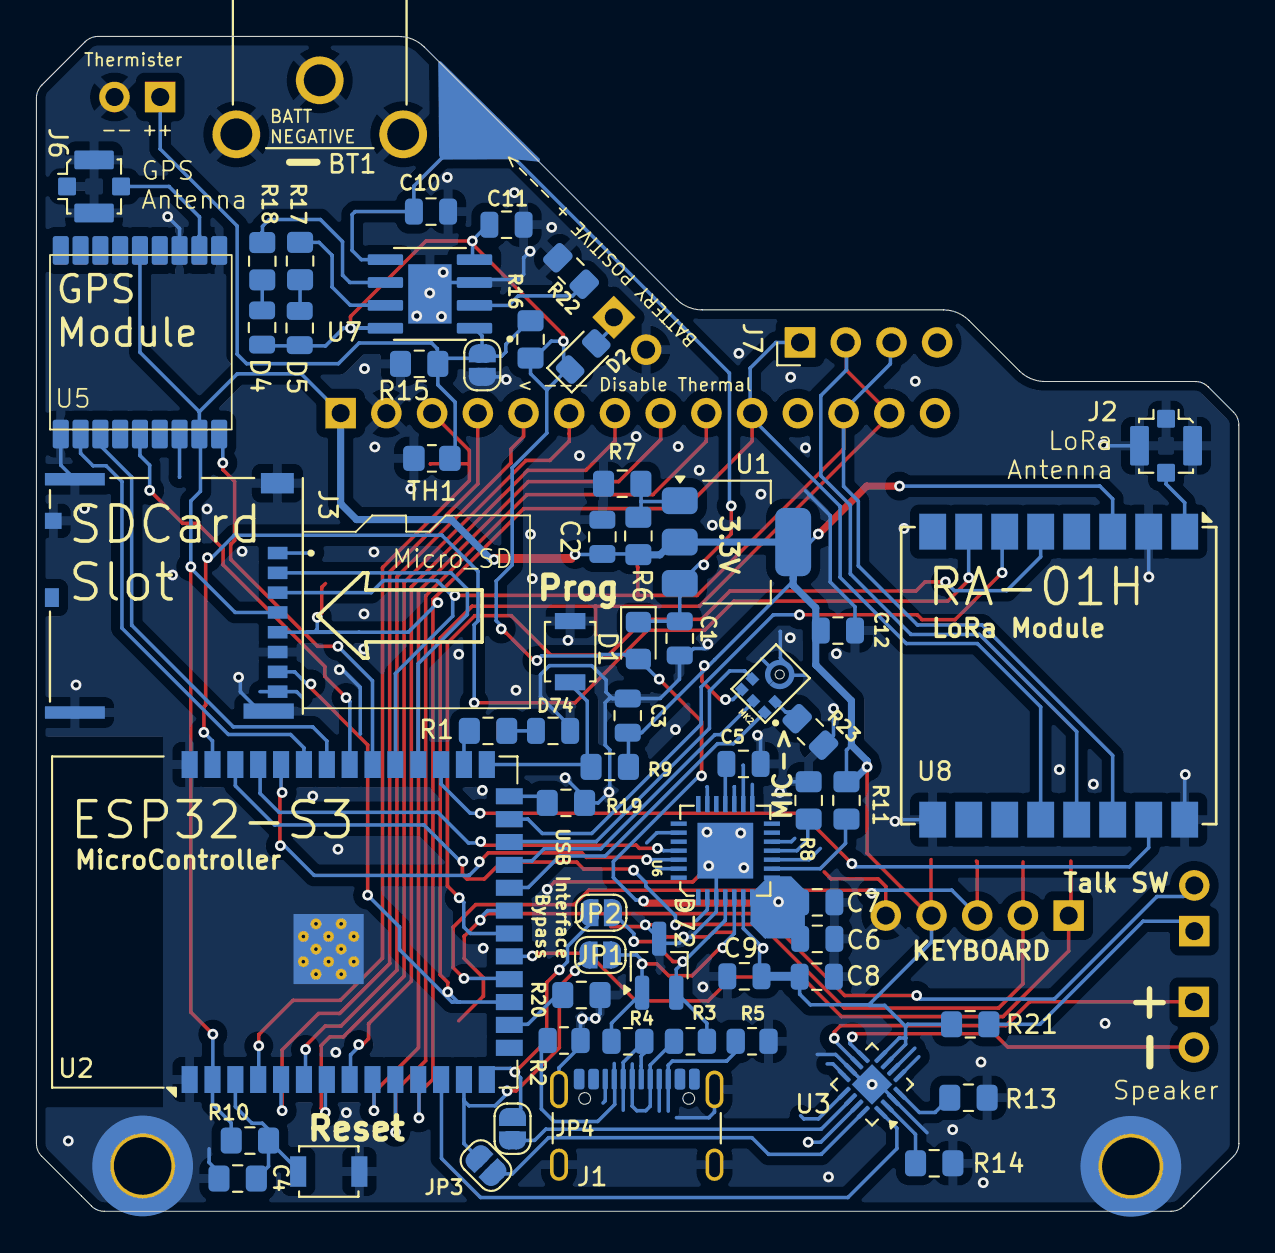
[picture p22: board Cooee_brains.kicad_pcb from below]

Board: 2 copper layers, 66.8 x 65.3 mm, 79 parts (63 on the bottom side), 68 nets.

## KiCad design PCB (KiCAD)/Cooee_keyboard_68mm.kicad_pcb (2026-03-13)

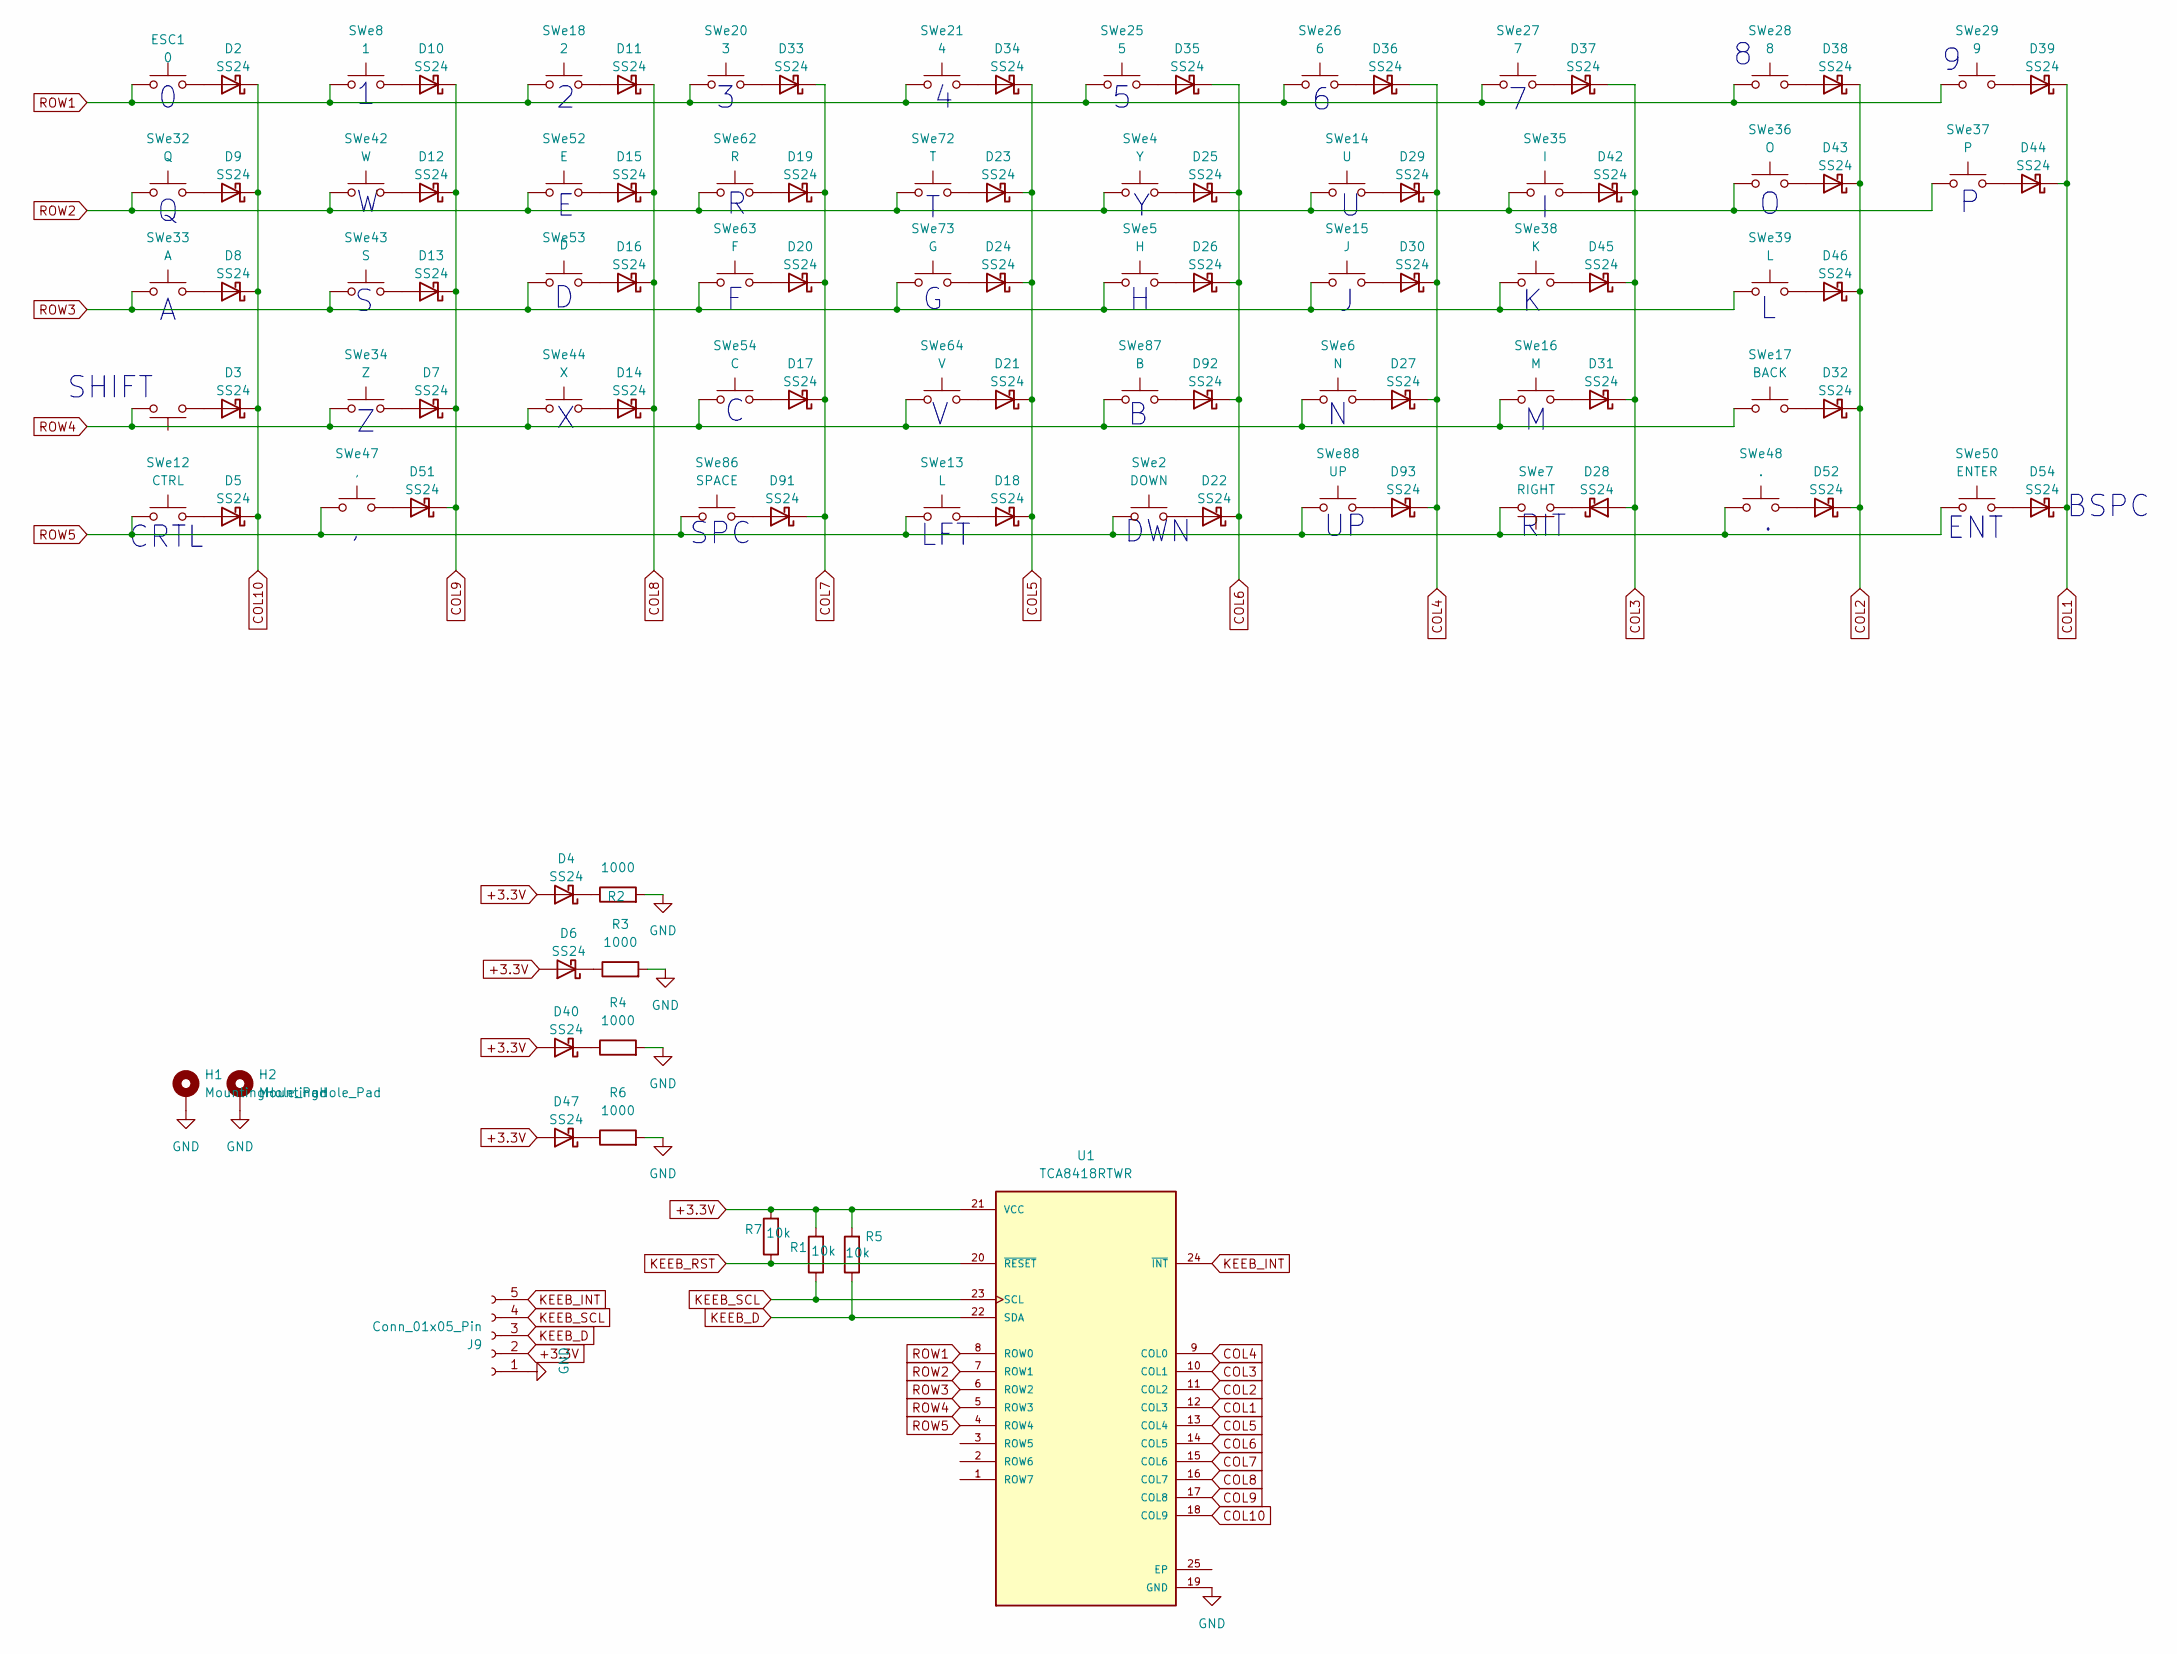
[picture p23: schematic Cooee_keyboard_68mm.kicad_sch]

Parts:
D2, D3, D4, D5, D6, D7, D8, D9, D10, D11, D12, D13, D14, D15, D16, D17, D18, D19, D20, D21, D22, D23, D24, D25, D26, D27, D28, D29, D30, D31, D32, D33, D34, D35, D36, D37, D38, D39, D40, D42, D43, D44, D45, D46, D47, D51, D52, D54, D91, D92, D93: SS24; D_0805_2012Metric
ESC1: 0; SW_SPST_B3U-1000P_MovedText
H1, H2: MountingHole_Pad; MountingHole_3.2mm_M3_DIN965_Pad_TopBottom
J9: Conn_01x05_Pin; PinHeader_1x05_P2.54mm_Horizontal
R1, R5, R7: 10k; R_0805_2012Metric_Pad1.20x1.40mm_HandSolder
R2, R3, R4, R6: 1000; R_0805_2012Metric_Pad1.20x1.40mm_HandSolder
SWe2: DOWN; SW_SPST_B3U-1000P_MovedText
SWe4: Y; SW_SPST_B3U-1000P_MovedText
SWe5: H; SW_SPST_B3U-1000P_MovedText
SWe6: N; SW_SPST_B3U-1000P_MovedText
SWe7: RIGHT; SW_SPST_B3U-1000P_MovedText
SWe8: 1; SW_SPST_B3U-1000P_MovedText
SWe12: CTRL; SW_SPST_B3U-1000P_MovedText
SWe13, SWe39: L; SW_SPST_B3U-1000P_MovedText
SWe14: U; SW_SPST_B3U-1000P_MovedText
SWe15: J; SW_SPST_B3U-1000P_MovedText
SWe16: M; SW_SPST_B3U-1000P_MovedText
SWe17: BACK; SW_SPST_B3U-1000P_MovedText
SWe18: 2; SW_SPST_B3U-1000P_MovedText
SWe20: 3; SW_SPST_B3U-1000P_MovedText
SWe21: 4; SW_SPST_B3U-1000P_MovedText
SWe24: SFT; SW_SPST_B3U-1000P_MovedText
SWe25: 5; SW_SPST_B3U-1000P_MovedText
SWe26: 6; SW_SPST_B3U-1000P_MovedText
SWe27: 7; SW_SPST_B3U-1000P_MovedText
SWe28: 8; SW_SPST_B3U-1000P_MovedText
SWe29: 9; SW_SPST_B3U-1000P_MovedText
SWe32: Q; SW_SPST_B3U-1000P_MovedText
SWe33: A; SW_SPST_B3U-1000P_MovedText
SWe34: Z; SW_SPST_B3U-1000P_MovedText
SWe35: I; SW_SPST_B3U-1000P_MovedText
SWe36: O; SW_SPST_B3U-1000P_MovedText
SWe37: P; SW_SPST_B3U-1000P_MovedText
SWe38: K; SW_SPST_B3U-1000P_MovedText
SWe42: W; SW_SPST_B3U-1000P_MovedText
SWe43: S; SW_SPST_B3U-1000P_MovedText
SWe44: X; SW_SPST_B3U-1000P_MovedText
SWe47: ,; SW_SPST_B3U-1000P_MovedText
SWe48: .; SW_SPST_B3U-1000P_MovedText
SWe50: ENTER; SW_SPST_B3U-1000P_MovedText
SWe52: E; SW_SPST_B3U-1000P_MovedText
SWe53: D; SW_SPST_B3U-1000P_MovedText
SWe54: C; SW_SPST_B3U-1000P_MovedText
SWe62: R; SW_SPST_B3U-1000P_MovedText
SWe63: F; SW_SPST_B3U-1000P_MovedText
SWe64: V; SW_SPST_B3U-1000P_MovedText
SWe72: T; SW_SPST_B3U-1000P_MovedText
SWe73: G; SW_SPST_B3U-1000P_MovedText
SWe86: SPACE; SW_SPST_B3U-1000P_MovedText
SWe87: B; SW_SPST_B3U-1000P_MovedText
SWe88: UP; SW_SPST_B3U-1000P_MovedText
U1: TCA8418RTWR; QFN50P400X400X100-25N; PARTREV G

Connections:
+3.3V: D4.2 (A), D6.2 (A), D40.2 (A), D47.2 (A), J9.2, R1.2, R5.2, R7.2, U1.21 (VCC)
COL1: D39.1 (K), D44.1 (K), D54.1 (K), U1.12 (COL3)
COL2: D32.1 (K), D38.1 (K), D43.1 (K), D46.1 (K), D52.1 (K), U1.11 (COL2)
COL3: D28.2 (A), D31.1 (K), D37.1 (K), D42.1 (K), D45.1 (K), U1.10 (COL1)
COL4: D27.1 (K), D29.1 (K), D30.1 (K), D36.1 (K), D93.1 (K), U1.9 (COL0)
COL5: D18.1 (K), D21.1 (K), D23.1 (K), D24.1 (K), D34.1 (K), U1.13 (COL4)
COL6: D22.1 (K), D25.1 (K), D26.1 (K), D35.1 (K), D92.1 (K), U1.14 (COL5)
COL7: D17.1 (K), D19.1 (K), D20.1 (K), D33.1 (K), D91.1 (K), U1.15 (COL6)
COL8: D11.1 (K), D14.1 (K), D15.1 (K), D16.1 (K), U1.16 (COL7)
COL9: D7.1 (K), D10.1 (K), D12.1 (K), D13.1 (K), D51.1 (K), U1.17 (COL8)
COL10: D2.1 (K), D3.1 (K), D5.1 (K), D8.1 (K), D9.1 (K), U1.18 (COL9)
GND: H1.1, H2.1, J9.1, R2.2, R3.2, R4.2, R6.2, U1.19 (GND)
KEEB_D: J9.3, R5.1, U1.22 (SDA)
KEEB_INT: J9.5, U1.24 (~INT)
KEEB_RST: R7.1, U1.20 (~RESET)
KEEB_SCL: J9.4, R1.1, U1.23 (SCL)
unnamed: D2.2 (A), ESC1.2
unnamed: D3.2 (A), SWe24.2
unnamed: D4.1 (K), R2.1
unnamed: D5.2 (A), SWe12.2
unnamed: D6.1 (K), R3.1
unnamed: D7.2 (A), SWe34.2
unnamed: D8.2 (A), SWe33.2
unnamed: D9.2 (A), SWe32.2
unnamed: D10.2 (A), SWe8.2
unnamed: D11.2 (A), SWe18.2
unnamed: D12.2 (A), SWe42.2
unnamed: D13.2 (A), SWe43.2
unnamed: D14.2 (A), SWe44.2
unnamed: D15.2 (A), SWe52.2
unnamed: D16.2 (A), SWe53.2
unnamed: D17.2 (A), SWe54.2
unnamed: D18.2 (A), SWe13.2
unnamed: D19.2 (A), SWe62.2
unnamed: D20.2 (A), SWe63.2
unnamed: D21.2 (A), SWe64.2
unnamed: D22.2 (A), SWe2.2
unnamed: D23.2 (A), SWe72.2
unnamed: D24.2 (A), SWe73.2
unnamed: D25.2 (A), SWe4.2
unnamed: D26.2 (A), SWe5.2
unnamed: D27.2 (A), SWe6.2
unnamed: D28.1 (K), SWe7.1
unnamed: D29.2 (A), SWe14.2
unnamed: D30.2 (A), SWe15.2
unnamed: D31.2 (A), SWe16.2
unnamed: D32.2 (A), SWe17.2
unnamed: D33.2 (A), SWe20.2
unnamed: D34.2 (A), SWe21.2
unnamed: D35.2 (A), SWe25.2
unnamed: D36.2 (A), SWe26.2
unnamed: D37.2 (A), SWe27.2
unnamed: D38.2 (A), SWe28.2
unnamed: D39.2 (A), SWe29.2
unnamed: D40.1 (K), R4.1
unnamed: D42.2 (A), SWe35.2
unnamed: D43.2 (A), SWe36.2
unnamed: D44.2 (A), SWe37.2
unnamed: D45.2 (A), SWe38.2
unnamed: D46.2 (A), SWe39.2
unnamed: D47.1 (K), R6.1
unnamed: D51.2 (A), SWe47.2
unnamed: D52.2 (A), SWe48.2
unnamed: D54.2 (A), SWe50.2
unnamed: D91.2 (A), SWe86.2
unnamed: D92.2 (A), SWe87.2
unnamed: D93.2 (A), SWe88.2
ROW1: ESC1.1, SWe8.1, SWe18.1, SWe20.1, SWe21.1, SWe25.1, SWe26.1, SWe27.1, SWe28.1, SWe29.1, U1.8 (ROW0)
ROW2: SWe4.1, SWe14.1, SWe32.1, SWe35.1, SWe36.1, SWe37.1, SWe42.1, SWe52.1, SWe62.1, SWe72.1, U1.7 (ROW1)
ROW3: SWe5.1, SWe15.1, SWe33.1, SWe38.1, SWe39.1, SWe43.1, SWe53.1, SWe63.1, SWe73.1, U1.6 (ROW2)
ROW4: SWe6.1, SWe16.1, SWe17.1, SWe24.1, SWe34.1, SWe44.1, SWe54.1, SWe64.1, SWe87.1, U1.5 (ROW3)
ROW5: SWe2.1, SWe7.2, SWe12.1, SWe13.1, SWe47.1, SWe48.1, SWe50.1, SWe86.1, SWe88.1, U1.4 (ROW4)

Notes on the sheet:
ENT
CRTL
LFT
SHIFT
DWN
SPC
RIT
BSPC

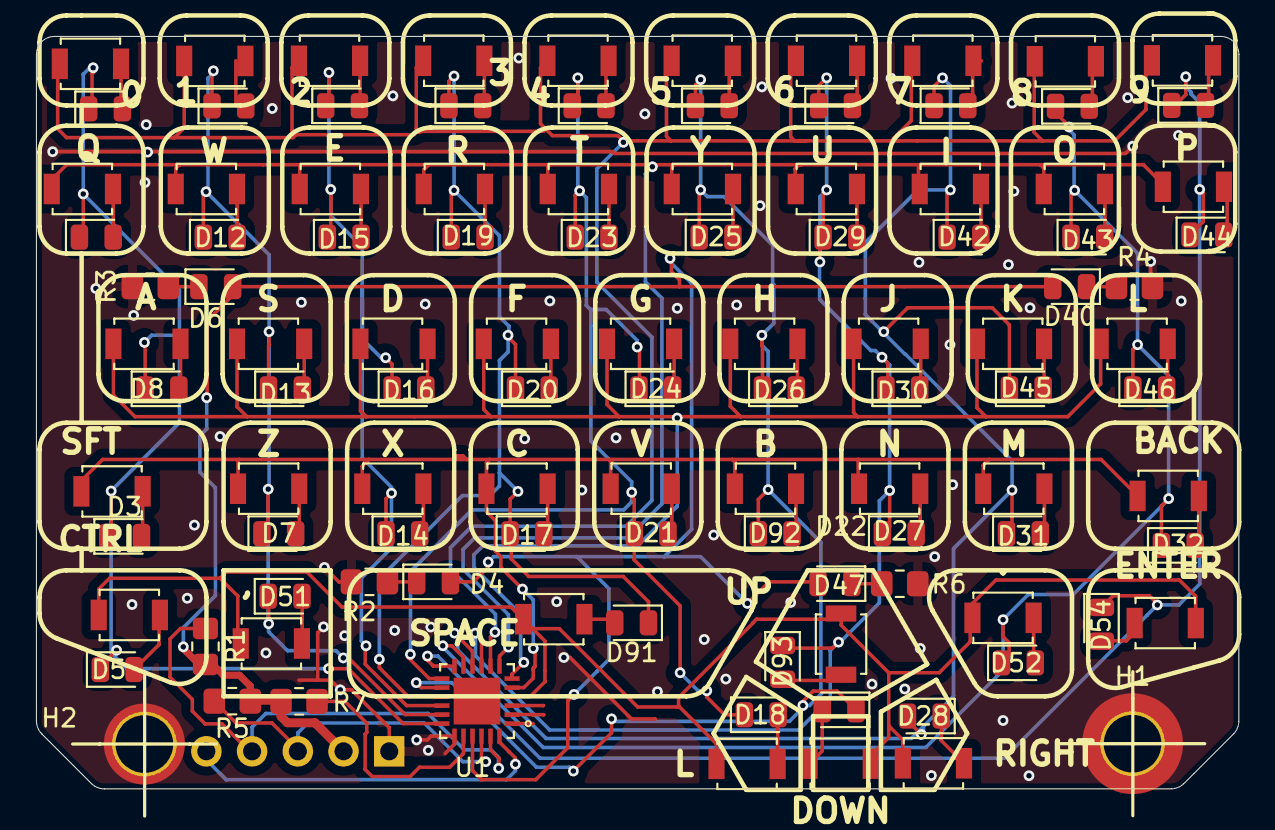
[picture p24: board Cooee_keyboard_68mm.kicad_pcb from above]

Board: 2 copper layers, 66.8 x 41.8 mm, 109 parts (1 on the bottom side), 72 nets.

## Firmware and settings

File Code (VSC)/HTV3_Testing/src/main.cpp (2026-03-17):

/* TODO
count the total number of full (32byte) packets we SHOULD have sent
count the number of times the programm reaches SendLoRaMessage Success
count the total number of recieved 32byte packets on the Rx end!
*/

// 320 samples = 0.04s of audio at 8000Hz
// 32 byte packet = 0.16s of audio at 8000Hz
// 80 bytes = 3200 samples = 0.4s of audio!

// DEBUG, remove later
int packets_filled = 0;
int packets_sent = 0;
int packets_recieved = 0;
int packets_played = 0;
bool prints = true;

#include <Arduino.h>
#include <SPI.h>
#include <Wire.h>
#include <RadioLib.h>
#include <Adafruit_SSD1306.h> //HTV3 OLED drivers
#include <cmath>
#include <cstring> // std::memcpy
#include "FS.h"
#include <LittleFS.h>
#include <driver/i2s.h>

/* - -----     ENABLE/DISABLE FEATURES ----- - */
// #define LCD_4ELECRO
// #define TOUCH_4ELECRO
#define MICROPHONE
#define SPEAKER
// #define GPS
// #define BATTERY
#define HT3_OLED
#define LORA_RADIO

const int bytes_per_sample = 2;
const int recording_length = 64;
const int audio_buffer_size = 1024;
static int16_t locally_saved_recording[audio_buffer_size * recording_length] = {0}; // enough for ~2 seconds of voice samples at 8KHz samplerate
static int16_t decoded_samples[audio_buffer_size * recording_length] = {0};         // enough for ~2 seconds of voice samples at 8KHz samplerate
int decoded_playable_index = 0;
int decoded_played_index = 0;

#ifdef SPEAKER //=====SPEAKER :  AUDIO OUT

#define SPEAKER_I2S_PORT I2S_NUM_1
#define SPEAKER_I2S_DOUT 48
#define SPEAKER_I2S_BCLK 47
#define SPEAKER_I2S_LRC 7

i2s_pin_config_t speaker_i2spins = {
    .bck_io_num = SPEAKER_I2S_BCLK,
    .ws_io_num = SPEAKER_I2S_LRC,
    .data_out_num = SPEAKER_I2S_DOUT,
    .data_in_num = I2S_PIN_NO_CHANGE};

i2s_config_t speaker_i2sconfig = {
    .mode = (i2s_mode_t)(I2S_MODE_MASTER | I2S_MODE_TX),
    .sample_rate = 8000,
    .bits_per_sample = I2S_BITS_PER_SAMPLE_16BIT,
    .channel_format = I2S_CHANNEL_FMT_ONLY_LEFT,
    .communication_format = I2S_COMM_FORMAT_STAND_I2S,
    .intr_alloc_flags = ESP_INTR_FLAG_LEVEL1,
    //.intr_alloc_flags = 0,
    .dma_buf_count = 2,
    .dma_buf_len = audio_buffer_size,
    .use_apll = false};

#endif

#ifdef LCD_4ELECRO
// Elecro 4.0 TFT needs adafruit_st7789 or TFT_eSPI (configured for ST7789 driver)
// the chipset is an ST7789
// resolution is 480x320
#include <TFT_eSPI.h>
TFT_eSPI tft = TFT_eSPI();
#endif

#ifdef TOUCH_4ELECRO
#include <XPT2046_Touchscreen.h>
// make an SPI for the TS
#define TS_MOSI 4
#define TS_MISO 2
#define TS_SCK 3
#define TS_CS 5

SPIClass ts_SPI = SPIClass(HSPI);
XPT2046_Touchscreen ts(TS_CS);
extern XPT2046_Touchscreen ts;
#endif

#ifdef MICROPHONE //=====MICROPHONE :  AUDIO IN

#define MIC_I2S_PORT I2S_NUM_0
#define MIC_I2S_DOUT 4
#define MIC_I2S_BCLK 5
#define MIC_I2S_LRC 3
#define MIC_CS 2
#include <codec2.h> //In the codec2 folder in the library folder

i2s_config_t mic_i2sconfig = {
    .mode = (i2s_mode_t)(I2S_MODE_MASTER | I2S_MODE_RX),
    .sample_rate = 16000, // this refuses to accep any values lower than 16000
    .bits_per_sample = I2S_BITS_PER_SAMPLE_16BIT,
    .channel_format = I2S_CHANNEL_FMT_ONLY_RIGHT,
    //.channel_format = I2S_CHANNEL_FMT_RIGHT_LEFT,
    .communication_format = I2S_COMM_FORMAT_STAND_I2S,
    .intr_alloc_flags = ESP_INTR_FLAG_LEVEL1,
    .dma_buf_count = 2,               // does this just multiply the value below? whats this about...
    .dma_buf_len = audio_buffer_size, // this value is in samples!
    .use_apll = false};

i2s_pin_config_t mic_i2spins = {
    .bck_io_num = MIC_I2S_BCLK,
    .ws_io_num = MIC_I2S_LRC,
    .data_out_num = I2S_PIN_NO_CHANGE,
    .data_in_num = MIC_I2S_DOUT};

#endif

#ifdef HT3_OLED
// Heltec OLED Pins
#define oled_scl 18
#define oled_sda 17
#define oled_rst 21
#define VEXT_PIN 36 // external voltage, needed to send power to the OLED display
#define OLED_WIDTH 128
#define OLED_HEIGHT 64
#endif

#define LED_Orange 1 // the orange LED seems to have a mind of it's own...
#define LED_W 35
#define BOOT_BTN 0

// LoRa module (SX1262) pins
#define LoRa_MOSI 10
#define LoRa_MISO 11
#define LoRa_SCK 9
#define LoRa_nss 8
#define LoRa_dio1 14
#define LoRa_nrst 12
#define LoRa_busy 13

#define LoRa_en_Tx 15
#define LoRa_en_Rx 16

#ifdef HT3_OLED
#define SCREEN_WIDTH 128
#define SCREEN_HEIGHT 64
#define OLED_ADDR 0x3C // Heltec default

Adafruit_SSD1306 display(
    SCREEN_WIDTH,
    SCREEN_HEIGHT,
    &Wire,
    oled_rst);
#endif

//-- AUDIO ENCODING --
struct CODEC2 *codec2_state;
#define ENCODE_FRAME_BYTES 8          // the 40byte frame/packet is built up gradually of 8byte chunks
#define ENCODE_CODEC2_PACKET_BYTES 96 // wait for 5 x 8byte frames before sending over LoRa
static uint8_t bytes_buffer_size = 480;
static uint8_t tx_encode_frame[ENCODE_CODEC2_PACKET_BYTES] = {0}; // 40 byte packet of compressed audio, this is the final array to actually be sent over radio
static uint8_t little_8byte_buffer[8] = {0};
static uint8_t tx_encode_frame_index = 0; // this tracks which of the 5 8byte chunks within the overall 40byte packet we are up to
// static int16_t samples_to_encode[320] = {0}; // this just contains a copy of the last 320 samples of audio which were copied to the locally_saved_recording buffer array, since the encoding function expects 320 samples only!
size_t transmitting_index = 0;

TaskHandle_t encode_task_;
int c2_samples_per_frame_;
int c2_bytes_per_frame_;
int16_t *c2_samples_;
uint8_t *c2_bits_;

// #define configMINIMAL_STACK_SIZE 2048 // Default is usually 256-512

enum Topic : uint8_t
{
  CONTROL = 0,
  TELEMETRY = 1,
  TRANSFER = 2,
  MESSAGE = 3,
  VOICE = 4,
  VIDEO = 5,
  IMAGE = 6,
  LOCATION = 7
};

struct LoRaPacket
{
  uint8_t senderID;     // 1 byte, unique per transmitter
  Topic topicID;        // 1 byte, or more if many topics
  uint8_t targetID;     // 1 byte, unique per target
  uint8_t payload[192]; // adjustable to stay under 200 bytes total
};

SX1262 radio = new Module(LoRa_nss, LoRa_dio1, LoRa_nrst, LoRa_busy);
String oled_message = "OLED Test!";

// function to generate a random string
String random_string(size_t length)
{
  static const char chars[] =
      "0123456789ABCDEFGHIJKLMNOPQRSTUVWXYZabcdefghijklmnopqrstuvwxyz";

  String s;
  for (int i = 0; i < length; i++)
  {
    s += chars[random(0, sizeof(chars) - 1)];
  }

  return s;
}

size_t recording_index = 0;
bool feedback = false;
int16_t GetAudioSamples(int16_t *buffer, size_t samples_to_get, bool give_level = false)
{
  // this must return 1024 samples, other audio buffer sizes don't work with this device
  int16_t input_gain = 40;
  int16_t temp_buffer[samples_to_get];
  size_t bytesRead;
  i2s_read(MIC_I2S_PORT, temp_buffer, samples_to_get * bytes_per_sample, &bytesRead, portMAX_DELAY);

  int16_t samples_average_value = 0;
  for (int i = 0; i < (bytesRead / 2); i += 2)
  {
    temp_buffer[i] *= input_gain;
    samples_average_value += abs(temp_buffer[i] >> 14);

    *(buffer + i / 2) = *(temp_buffer + i);
  }

  samples_average_value /= (bytesRead / 2);
  return samples_average_value;
}

void SaveSamples()
{

  if (prints)
  {
    Serial.println("Here's all the samples: ");
  }

  for (int16_t sample : locally_saved_recording)
  {
    Serial.print(String(sample) + ",");
  }

  /*
  File file = LittleFS.open("/hello.txt", FILE_WRITE);
  if (!file)
  {
    Serial.println("Failed to open file for writing");
    return;
  }

  // write some data
  file.println("Hello ESP32");
  file.close(); // close the file – flushes the buffer

  Serial.println("Wrote /hello.txt");
  */
}

void SendLoRaMessage(String msg)
{
  if (prints)
  {
    Serial.println("SendLoRaMessage() called in text mode");
  }
  int result = radio.transmit(msg);

  if (result == RADIOLIB_ERR_NONE)
  { // the packet was successfully transmitted
    if (prints)
    {
      Serial.println(F("Success!"));
    }
  }
  else if (result == RADIOLIB_ERR_PACKET_TOO_LONG)
  { // the supplied packet was longer than 256 bytes
    Serial.println(F("too long!"));
  }
  else if (result == RADIOLIB_ERR_TX_TIMEOUT)
  { // timeout occured while transmitting packet
    Serial.println(F("timeout occured while transmitting packet!"));
  }
  else
  { // some other error occurred
    Serial.print(F("transmit failed, code "));
    Serial.println(result);
  }
}

void SendLoRaMessage(uint8_t *data, size_t len)
{
  if (prints)
  {
    Serial.println("SendLoRaMessage() called in data mode");
  }

  int result = radio.transmit(data, len);

  if (result == RADIOLIB_ERR_NONE)
  { // the packet was successfully transmitted
    if (prints)
    {
      Serial.println(F("Success!"));
    }
    packets_sent++;
  }
  else if (result == RADIOLIB_ERR_PACKET_TOO_LONG)
  { // the supplied packet was longer than 256 bytes
    Serial.println(F("too long!"));
  }
  else if (result == RADIOLIB_ERR_TX_TIMEOUT)
  { // timeout occured while transmitting packet
    Serial.println(F("Radio timed OUT while sending"));
  }
  else
  { // some other error occurred
    Serial.print(F("transmit failed, code "));
    Serial.println(result);
  }
}

void PutOnScreen(String msg, bool clear)
{
  if (clear)
  {
    oled_message = msg;
  }
  else
  {
    oled_message = oled_message + msg;
  }
}

static byte recievedCompressedBytes[480] = {0};
int ready_for_decoding_index = 0;
int decoded_index = 0;
static int16_t recievedDecompressedSamples[1024 * 5] = {0};
int decompressedPlayed_index = 0;

void RecieveLoRaMessage()
{
  // PutOnScreen("Awaiting message...", false);

  // you can receive data as an Arduino String
  // NOTE: receive() is a blocking method!
  //       See example ReceiveInterrupt for details
  //       on non-blocking reception method.
  // String str;
  // int state = radio.receive(str);

  // you can also receive data as byte array

  byte byteArr[ENCODE_CODEC2_PACKET_BYTES];
  int state = radio.receive(byteArr, ENCODE_CODEC2_PACKET_BYTES);

  if (state == RADIOLIB_ERR_NONE) // everything recieved fine
  {
    if (prints)
    {
      Serial.println("A message has been heard!");
    }
    packets_recieved++;

    // move these successfully heard compressed audio bytes into our static ring buffer for the other compression loop to handle in time
    for (int i = 0; i < ENCODE_CODEC2_PACKET_BYTES; i++)
    {
      recievedCompressedBytes[ready_for_decoding_index + i] = byteArr[i];
    }
    ready_for_decoding_index += ENCODE_CODEC2_PACKET_BYTES;
    if (ready_for_decoding_index > 320) // wrap this buffer
    {
      ready_for_decoding_index -= 320;
    }

    if (prints)
    {
      Serial.println("Recieved bytes added to buffer, ready for decoding then playing. ready_for_decoding_index = " + (String)ready_for_decoding_index);
    }
    /*
    Serial.println(F("success!"));

    // print the data of the packet
    Serial.print(F("[SX1262] Data:\t\t"));
    Serial.println(str);
    PutOnScreen("Recieved: " + str, false);

    // print the RSSI (Received Signal Strength Indicator)
    // of the last received packet
    Serial.print(F("[SX1262] RSSI:\t\t"));
    Serial.print(radio.getRSSI());
    Serial.println(F(" dBm"));

    // print the SNR (Signal-to-Noise Ratio)
    // of the last received packet
    Serial.print(F("[SX1262] SNR:\t\t"));
    Serial.print(radio.getSNR());
    Serial.println(F(" dB"));
    */
  }
  else if (state == RADIOLIB_ERR_RX_TIMEOUT)
  {
    // timeout occurred while waiting for a packet
    if (prints)
    {
      Serial.println(F("Listening..."));
    }
  }
  else if (state == RADIOLIB_ERR_CRC_MISMATCH)
  {
    // packet was received, but is malformed
    Serial.println(F("CRC error!"));
  }
  else
  {
    // some other error occurred
    Serial.print(F("failed, code "));
    Serial.println(state);
  }
}

int GetTransmitDelta()
{
  int transmit_delta = 0;
  if (recording_index < transmitting_index)
  {
    transmit_delta = (recording_index + (audio_buffer_size * recording_length)) - transmitting_index;
  }
  else
  {
    transmit_delta = (recording_index - transmitting_index);
  }
  return transmit_delta;
}

int GetPlayedDelta()
{
  int played_delta = 0;
  if (decoded_playable_index < decoded_played_index)
  {
    played_delta = decoded_playable_index + (audio_buffer_size * recording_length) - decoded_played_index;
  }
  else
  {
    played_delta = decoded_playable_index - decoded_played_index;
  }

  return played_delta;
}

int GetRecieveDelta()
{
  int rx_delta = 0;
  if (ready_for_decoding_index < decoded_index)
  {
    rx_delta = ready_for_decoding_index + 320 - decoded_index;
  }
  else
  {
    rx_delta = (ready_for_decoding_index - decoded_index);
  }
  return rx_delta;
}

void StopSpeaker()
{
  // Stop playback:
  i2s_zero_dma_buffer(SPEAKER_I2S_PORT); // Clear any remaining data
  i2s_stop(SPEAKER_I2S_PORT);
}

void StartSpeaker()
{
  // Restart
  i2s_start(SPEAKER_I2S_PORT);
}

void encode_task(void *param)
{
  Serial.println("encode_task() started!");

  // Initialize the Codec2 object
  codec2_state = codec2_create(CODEC2_MODE_1600);
  if (codec2_state == NULL)
  {
    Serial.println("ERROR: Failed to create codec2 state!");
    return;
  }

  while (true)
  { // loop

    // check if we need to decode (any undecoded audio recieved)
    if (GetRecieveDelta() > 8)
    {
      if (prints)
      {
        Serial.println("More than 8 undecoded bytes in the buffer for decoding");
      }
      byte byteArr[8] = {0};
      for (int i = 0; i < 8; i++) // move 8 bytes into this little buffer to get decoded
      {
        // ensure that this doesn't go out of bounds
        if (decoded_index + i < 320)
        {
          byteArr[i] = recievedCompressedBytes[decoded_index + i];
        }
        else
        {
          byteArr[i] = recievedCompressedBytes[decoded_index + i - 320];
        }
      }
      decoded_index += 8;
      if (decoded_index > 320)
      {
        decoded_index -= 320;
      }

      if (prints)
      {
        Serial.println("Now decoding the 8 byte frame");
      }
      // int16_t decompressed_audio[320];
      codec2_decode(codec2_state, &decoded_samples[decoded_playable_index], byteArr);
      size_t bytes_written;
      decoded_playable_index += 320;
      int decoded_samples_buffer_size = (audio_buffer_size * recording_length);
      if (decoded_playable_index > decoded_samples_buffer_size)
      {
        decoded_playable_index -= decoded_samples_buffer_size;
      }
      if (prints)
      {
        Serial.println("Decoded frame into 320 samples, added to buffer, playable_index is now:" + (String)decoded_playable_index);
      }
      // we can only play whole buffers to the speaker of 1024 samples! so we must store out decodes, little by little
    }

    // check if we need to do an ecode (more than 320 new samples)
    if (GetTransmitDelta() >= 320)
    {
      if (prints)
      {
        Serial.println("transmit_delta above 320, moving samples to encoding buffer. Delta=" + (String)GetTransmitDelta());
      }
      // scrape the next 320 samples from the ring buffer to encode and send

      int16_t samples_to_encode[320] = {0};
      for (int i = 0; i < 320; i++)
      {
        if (transmitting_index + i < (audio_buffer_size * recording_length))
        {
          samples_to_encode[i] = locally_saved_recording[transmitting_index + i]; // copy 1 to 1 if the index stays within the bounds of locally_saved_recording[]
        }
        else
        { // otherwise we need to modify i to stay within bounds
          samples_to_encode[i] = locally_saved_recording[transmitting_index + i - (audio_buffer_size * recording_length)];
        }
      }
      transmitting_index += 320;
      if (transmitting_index >= (audio_buffer_size * recording_length)) // wrap around the array
      {
        transmitting_index -= (audio_buffer_size * recording_length);
      }

      // codec2_encode
      codec2_encode(codec2_state, tx_encode_frame + tx_encode_frame_index, samples_to_encode);
      vTaskDelay(1);

      // Send tx_encode_frame via radio etc
      if (prints)
      {
        Serial.println("320 samples converted to 8 bytes of compressed audio in frame buffer");
      }
      // Store this encoded 320samples -> 8bytes of compressed audio, into the 'tx_encode_frame'  buffer, we will sent it over lora once we collect 40 total bytes
      tx_encode_frame_index += ENCODE_FRAME_BYTES;             // incrememnt by 8bytes
      if (tx_encode_frame_index >= ENCODE_CODEC2_PACKET_BYTES) // packet is full (32 bytes)
      {
        packets_filled++;
        // Serial.println("32 byte frame buffer is full now");
        tx_encode_frame_index = 0;
        if (prints)
        {
          Serial.println("Sending: 32 bytes of comressed audio over LoRa");
        }
        SendLoRaMessage(tx_encode_frame, sizeof(tx_encode_frame));
      }
    }
    else
    {
      // Serial.println("Nothin new to encode...");
      delay(20);
    }
  }

  // this should never get reached, since the loop has no end
  //  cleanup the task before it ends or it will crash the chip
  codec2_destroy(codec2_state);
  vTaskDelete(NULL);
  return;
}

void setup()
{
  Serial.begin(115200);

  /*
  // initialise the file‑system
  Serial.println("Attempting to mount LittleFS.");
  delay(1000);
  if (!LittleFS.begin())
  { // false = mounting failed
    Serial.println("LittleFS mount failed");
    return;
  }
  Serial.println("LittleFS mounted");
  */

#ifdef SPEAKER
  i2s_driver_install(SPEAKER_I2S_PORT, &speaker_i2sconfig, 0, NULL);
  i2s_set_pin(SPEAKER_I2S_PORT, &speaker_i2spins);
#endif

#ifdef MICROPHONE
  i2s_driver_install(MIC_I2S_PORT, &mic_i2sconfig, 0, NULL);
  i2s_set_pin(MIC_I2S_PORT, &mic_i2spins);
#endif

#ifdef LCD_4ELECRO
  Serial.println("Initializing TFT...");
  tft.begin();
  tft.setRotation(0);
  delay(100);
  tft.fillScreen(TFT_BLACK);
  // tft.fillRect(100,100,200,200,TFT_GREEN);
  tft.setTextFont(2);
  tft.setTextSize(1);
  tft.setTextColor(TFT_WHITE);
  Serial.println("TFT Initialized!");
#endif

#ifdef TOUCH_4ELECRO
  ts_SPI.begin(TS_SCK, TS_MISO, TS_MOSI, TS_CS);
  ts.begin(ts_SPI);
  ts.setRotation(2);
#endif

  pinMode(MIC_CS, OUTPUT);
  digitalWrite(MIC_CS, HIGH);
  pinMode(LED_W, OUTPUT);
  pinMode(LED_Orange, OUTPUT);
  pinMode(BOOT_BTN, INPUT_PULLUP);
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
void loop()
{

#ifdef LCD_4ELECRO
  tft.fillScreen(TFT_BLACK);
  tft.setCursor(0, 0);
#endif

#ifdef TOUCH_4ELECRO
  boolean istouched = ts.touched();
  if (istouched)
  {
    // tft.print("a");
    TS_Point p = calibratedPoint(ts.getPoint());
    // tft.print( p.x );
    tft.fillCircle(p.x, p.y, 5, TFT_WHITE);
    tft.drawCircle(p.x, p.y, 50, TFT_WHITE);
  }
#endif

#ifdef HT3_OLED
  display.clearDisplay();
#endif

  if (digitalRead(BOOT_BTN) == LOW) // PRG button pressed down - we speak
  {
    if (!transmitting)
    {
      transmitting = true;
    }
  }
  else // PRG button is up - we listen
  {
    if (transmitting)
    {
      transmitting = false;
      delay(300);
    }
  }

  if (transmitting) // record the MIC_IN adc (should be talking)
  {
    // before we add 2048 bytes of data to locally_saved_recording we need to ensure that it can fit
    if ((recording_index + audio_buffer_size) < (audio_buffer_size * recording_length))
    {
      // enough room in array for new samples, starting at recording_index
    }
    else
    {
      // not enough room!
      recording_index = 0;

      // FIXME: this isn't ideal, it's better than writing outside the bounds, but the code that reads the locally_saved_recording[] array will still read the little left over part of the array that we're skipping!
    }

    int16_t ave_value = GetAudioSamples(&locally_saved_recording[recording_index], audio_buffer_size, true);
    recording_index += audio_buffer_size / 2;                      // 512, we are halving this because we only actually save half of them, the microphone samples at twice the rate we want (minimum device rate)
    if (recording_index >= (audio_buffer_size * recording_length)) // wrap around the array
    {
      recording_index -= (audio_buffer_size * recording_length);
    }
    if (prints)
    {
      Serial.println("recording_index @: " + String(recording_index) + ", transmitting_index @: " + String(transmitting_index));
    }
  }
  else
  {

    RecieveLoRaMessage();

    if (prints)
    {
      Serial.println("Rx'ed " + (String)ready_for_decoding_index);
    }

    if (GetPlayedDelta() > audio_buffer_size) // we have recieved and decoded enough samples to play to the speaker device
    {
      Serial.println("More than 1024 samples in the ready to play buffer!");
      size_t bytes_written = 0;
      esp_err_t err = i2s_write(SPEAKER_I2S_PORT, &decoded_samples[decoded_played_index], audio_buffer_size * 2, &bytes_written, portMAX_DELAY);
      if (err != ESP_OK)
      {
        Serial.print("An error occured while trying to send audio to speaker: " + err);
      }
      else
      {
        packets_played++;
      }

      decoded_played_index += audio_buffer_size;
      if (decoded_played_index > (audio_buffer_size * recording_length))
      {
        decoded_played_index -= (audio_buffer_size * recording_length);
      }
      if (prints)
      {
        Serial.println("Done writing 1024 samples to the speaker. Played: " + (String)decoded_played_index);
      }
    }
  }

#ifdef HT3_OLED
  display.setCursor(0, 0);
  display.setTextSize(2);
  oled_message = "Filled:" + (String)packets_filled + "\nSent:  " + (String)packets_sent + "\nRx:   " + (String)packets_recieved + "\nPlayed:" + (String)packets_played;

  display.print(oled_message);
  if (blink)
  {
    display.fillCircle(124, 60, 2, SSD1306_WHITE);
  }
  display.display();
#endif

  blink = !blink;
}

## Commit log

2026-01-09 initial commit of PCB project
    initial commit of PCB project
    [3D-DMG48270C043-04WTC.stp, Cooee.kicad_pcb, Cooee.kicad_sch]
2026-01-10 split PCB into 2 PCB's
    now has multiple PCB's one for computer and one for the keyboard
    [Cooee.kicad_sch, Cooee_brains.kicad_pcb, Cooee_brains.kicad_sch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]
2026-01-10 changed computer PCB edge shape to match keyboard
    So these can be 2x 2layer boards back to back, easy PnP/hotplate assembly, more modular (replaceable keyboards)
    [Cooee_brains.kicad_pcb, Cooee_brains.kicad_sch, Cooee_keyboard.kicad_pcb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]
2026-01-10 initial commit of CAD assembly
    initial commit of CAD assembly
    [18650.FCStd, Case.FCStd, Case_Assembly.FCStd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]
2026-01-15 more
    i write enough of these for work
    [18650.FCStd, Case.FCStd, Case_Assembly.FCStd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]
2026-01-16 finished routing new smaller keyboard
    finished routing new smaller keyboard
    [18650.FCStd, Case.FCStd, Case_2.FCStd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]
2026-01-17 finished keyboard at 67mm
    started work on esp32 motherboard
    [Cooee_brains.kicad_pcb, Cooee_brains.kicad_sch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]
2026-01-19 motherboard PCB layout work
    motherboard PCB layout work
    [18650.FCStd, Case.FCStd, Case_2.FCStd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]
2026-01-24 swapped out complex SX1262 circuitry for a module
    swapped out complex SX1262 circuitry for a module
    [Cooee_brains.kicad_pcb, Cooee_brains.kicad_sch, SX1262.kicad_sch]
2026-01-24 removed kiCad auto-backups from tracked files
    yeah
2026-01-26 cleaned up the silkscreen for keyboard PCB
    cleaned up the silkscreen for keyboard PCB, ordered prototypes
    [Case_2.FCStd, Case_Assembly.FCStd, Cooee_Brains.FCStd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]
2026-02-02 more PCB work
    should have the 90 degree SMD header pins lined up to mount now, unfortunately I've invalidated the keyboard prototypes I already bought
    [Case Prototype.step, Cooee_brains.kicad_pcb, Cooee_brains.kicad_sch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]
2026-02-07 new IC choices for GPS, audio and power
    also added a keyboard IC to the keyboard to preventing wasting precious ESP32 GPIOs
    [Cooee_brains.kicad_sch, Cooee_keyboard_68mm.kicad_pcb, Cooee_keyboard_68mm.kicad_sch]
2026-02-14 adding some of my coding work
    currently I'm just trying to get audio tranferred over LoRa using two heltecv3.2 boards. All I have so far is reading the microphone in
2026-02-19 finalized next prototype of keyboard PCB, ready to order
    finalized next prototype of keyboard PCB, ready to order
    [Cooee_brains.kicad_pcb, Cooee_brains.kicad_sch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]
2026-02-20 pcb layout work on phone motherboard
    pcb layout work on phone motherboard
    [Cooee_brains.kicad_pcb, Cooee_brains.kicad_sch, Cooee_keyboard_68mm.step]
2026-02-21 more PCB work on the motherboard
    more PCB work on the motherboard
    [Cooee_brains.kicad_pcb, Cooee_brains.kicad_sch]
2026-02-23 motherboard PCB work
    motherboard PCB work
    [Cooee_brains.kicad_pcb, Cooee_brains.kicad_sch]
2026-02-28 trying to figure out the dang i2s device configurations
    trying to figure out the dang i2s device configurations
    [Cooee_brains.kicad_pcb, Cooee_brains.kicad_sch]
2026-03-05 hacked the device sample rates
    half the microphone samples are not discarded due to it's minimum sample rate of 16kHz
2026-03-07 centred the USB port and screen properly
    centred the USB port and screen properly. trying to implement compressed audio over radio but compression function started throwing stack overflow
    [Cooee_brains.kicad_pcb, Cooee_brains.kicad_sch, Cooee_keyboard_68mm.kicad_pcb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]
2026-03-11 got past the stack overflow when encoding audio samples
    got past the stack overflow when encoding audio samples
    [Cooee_brains.kicad_pcb, Cooee_brains.kicad_sch]
2026-03-12 pcb work
    pcb work
    [Cooee_brains.kicad_pcb, Cooee_brains.kicad_sch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]
2026-03-13 fixed up some incorrect footprints/symbols
    fixed up some incorrect footprints/symbols
    [Cooee_brains-B_Cu.gbr, Cooee_brains-B_Mask.gbr, Cooee_brains-B_Paste.gbr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]
2026-03-14 Expanded README with philosophy section
    Added a philosophy section outlining the design principles and ideals for the Cooee device, focusing on simplicity, repairability, and hardware ownership.
2026-03-14 debugging the encoding and sending of voice data
    debugging the encoding and sending of voice data
    [Cooee_brains.kicad_sch]
2026-03-17 solidworks parts experimenteing, latest code
    solidworks parts experimenteing, latest code
    [Case2.SLDDRW, Case2.SLDPRT, CaseTest.SLDPRT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]
